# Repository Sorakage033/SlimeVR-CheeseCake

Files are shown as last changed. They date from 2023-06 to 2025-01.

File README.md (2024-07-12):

Intro-GIF 

# SlimeVR-CheeseCake
Very delicious Cheesecake. Designed by Sorakage

# OverView
"CheeseCake" is a Lighter, portable and better looking full body tracking device.   
Based on SlimeVR   
With 8-port charging dock, eliminating wiring troubles.   
# CAUTION：   
**When you place an order in JLCPCB, remember change the PCB thickness to 1mm!**    
    
**Before flashing the firmware, the board must be connected to the battery.**    
This design removes the protection diode (to prevent Li-po battery overcharged while uploading firmware), and USB-5V is supplied to the battery via the on-board charging chip TP4057.    
**The on-board charger will not output voltage without connected to the battery.**        
## Extra Info:      
Any kind of modification are welcome!         
It can be even better if you can credit me on the modified PCB with [\[This LOGO\]](999-PictureFiles/SK-LOGO.png)     

## Index
- [Components](#Components)
- [Versions](#Versions)
- [Printing](#Printing)
- [Assembly](#Assembly)
- [Support Link](#Support)

## Components 
For the CheeseCake you will need the following components:   
- PCB produced by JLC PCBA   
- 3D Print Parts   
- 38 or 40mm straps   
-   Li-po Battery (_803035 800/900mAh or 903035 1000/1200mAh is what the docs suggest_)
    -   **Ensure the battery is no larger than 9mm in depth, 30mm in width, and 35mm in height to fit the case.**
    -   **Verify the battery dimensions with the seller before purchase. Some sellers list 803035 batteries with dimensions exceed, which will not fit in the 3D printed case.**
- Pogo Pins (Optional for specific supported PCBs) [\[More Info\]](001-‘’Cheese‘’/POGOPIN%20purchase%20Link.txt)
- Soldering Iron/Station 

## Versions
There are lots of Variations of PCB included in this Project:     

### 1st Anniversary Special Edition
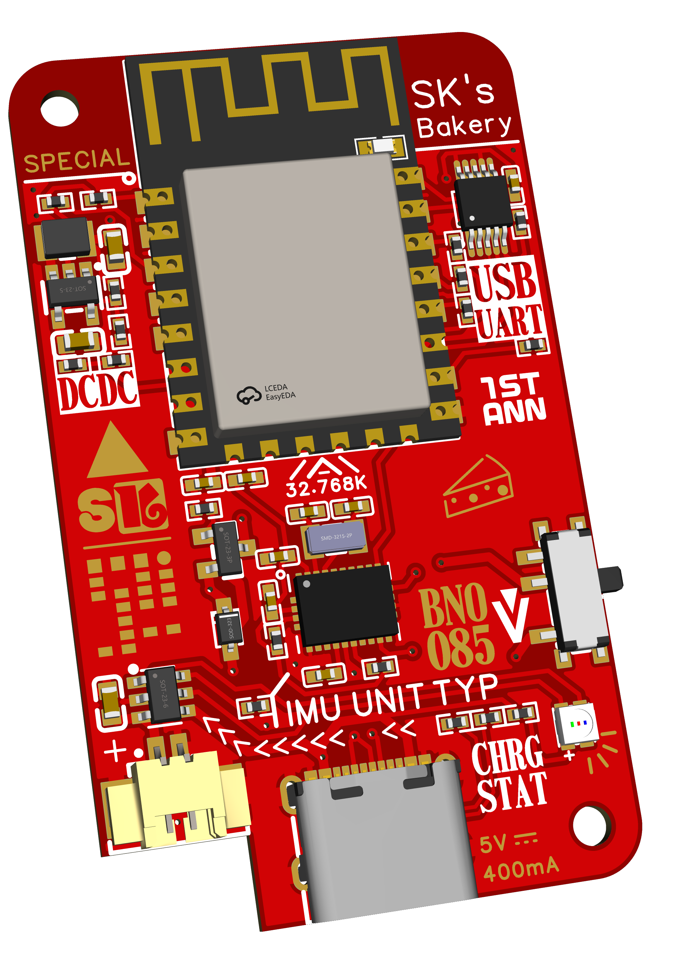
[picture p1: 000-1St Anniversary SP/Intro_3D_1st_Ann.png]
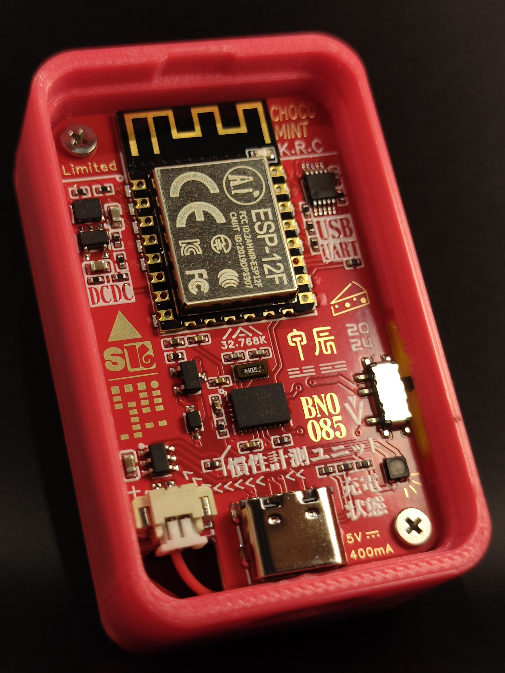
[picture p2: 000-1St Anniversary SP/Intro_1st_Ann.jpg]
      

It's been a year since the release of the cheesecake. To thank everyone for actively participating in enjoying cheesecakes, a special 1st Anniversary edition was released!    
It includes: BNO085(SMT Type), DC-DC Buck, and battery connector(JST 1.25mm)!

### BMI270-「Cheese RV」
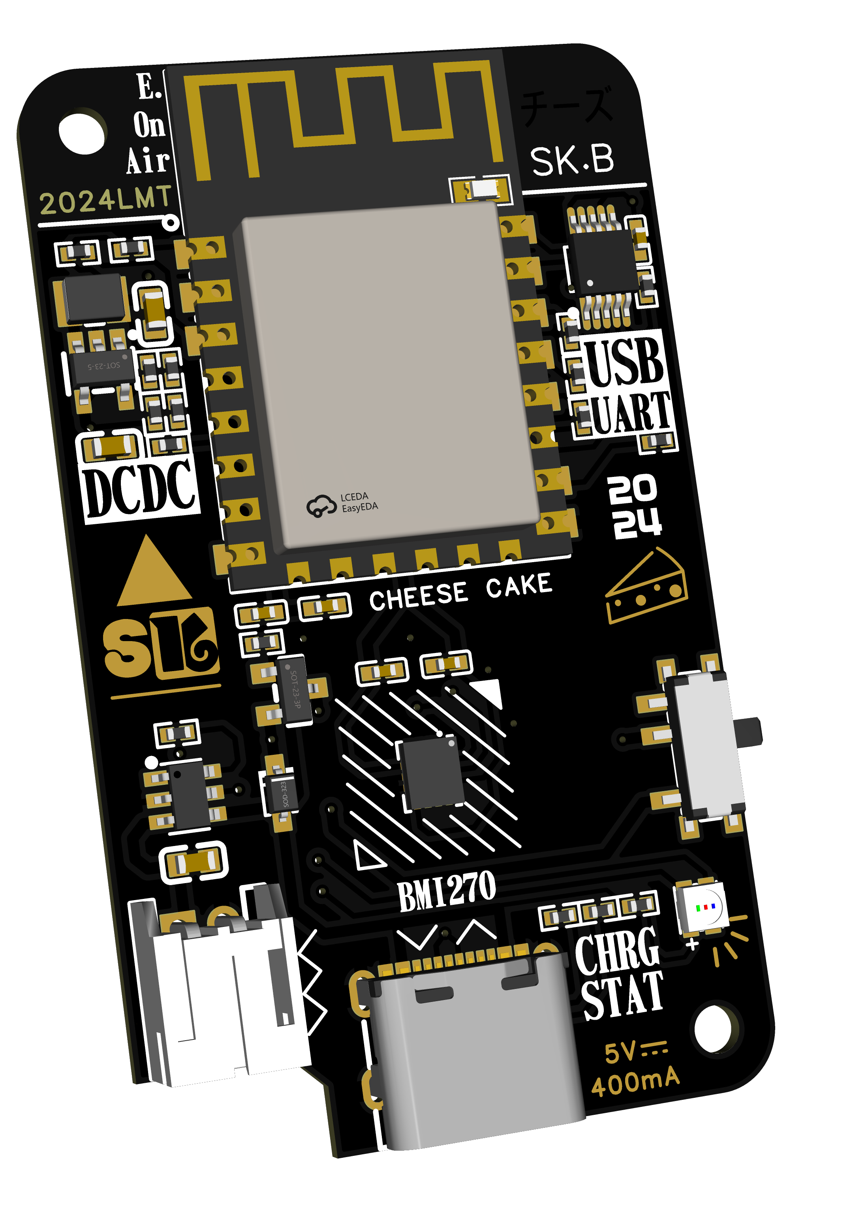
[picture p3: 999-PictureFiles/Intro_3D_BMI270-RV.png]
   

Because BMI160 is EOL now, Update a BMI270 version, it has a JST 2.0mm battery connector(Battery+ is left) and reverse to match Type-C Charging Dock.      
But it doesn't include AUX connector, if you want make a BMI270 with AUX, check "Cheese with AUX".       

### BNO085-「Choco」SpecialRemake
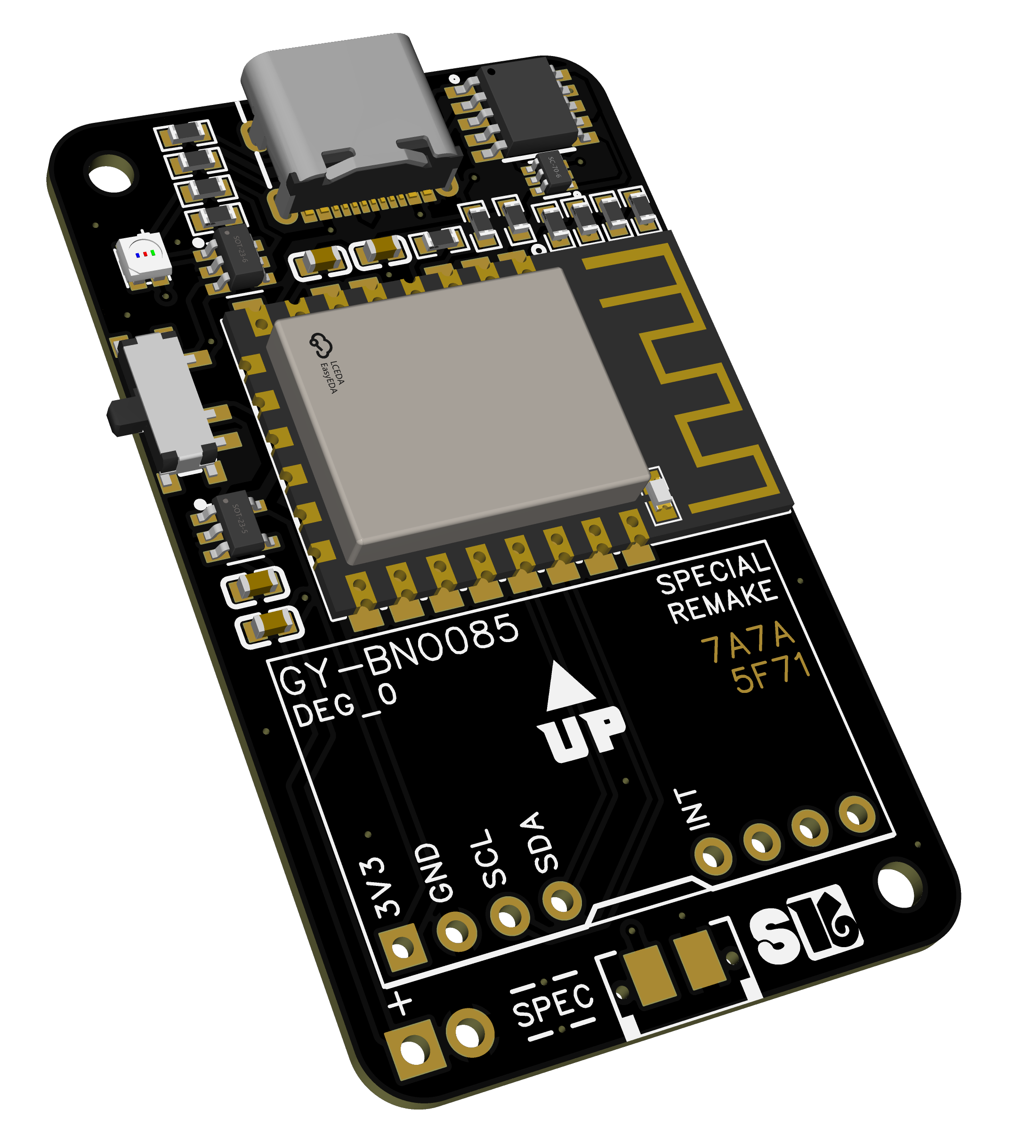
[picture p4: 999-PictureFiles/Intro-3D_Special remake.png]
    

### BNO085-「Choco」SpecialRemake(With AUX port)
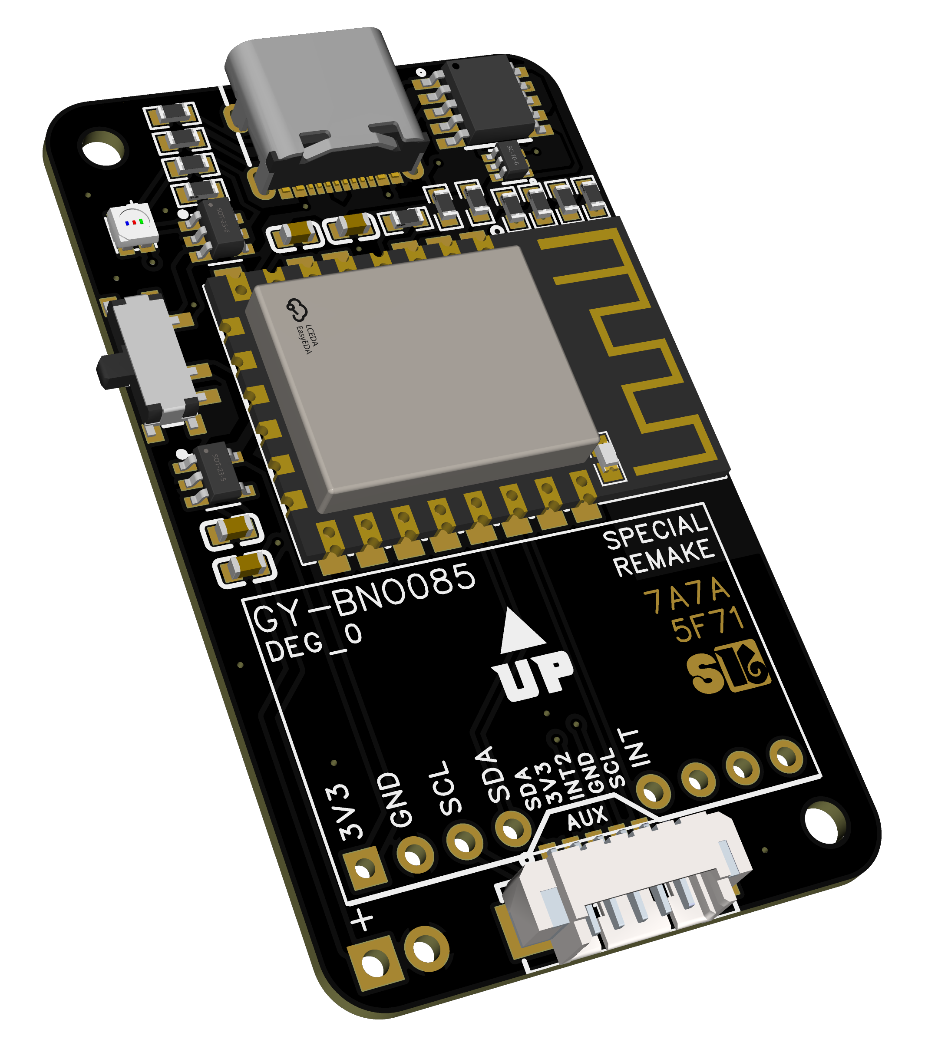
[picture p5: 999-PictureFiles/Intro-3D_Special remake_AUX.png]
    

### BNO085-「Choco」SpecialRemake(With AUX port and DC-DC Buck power supply)    
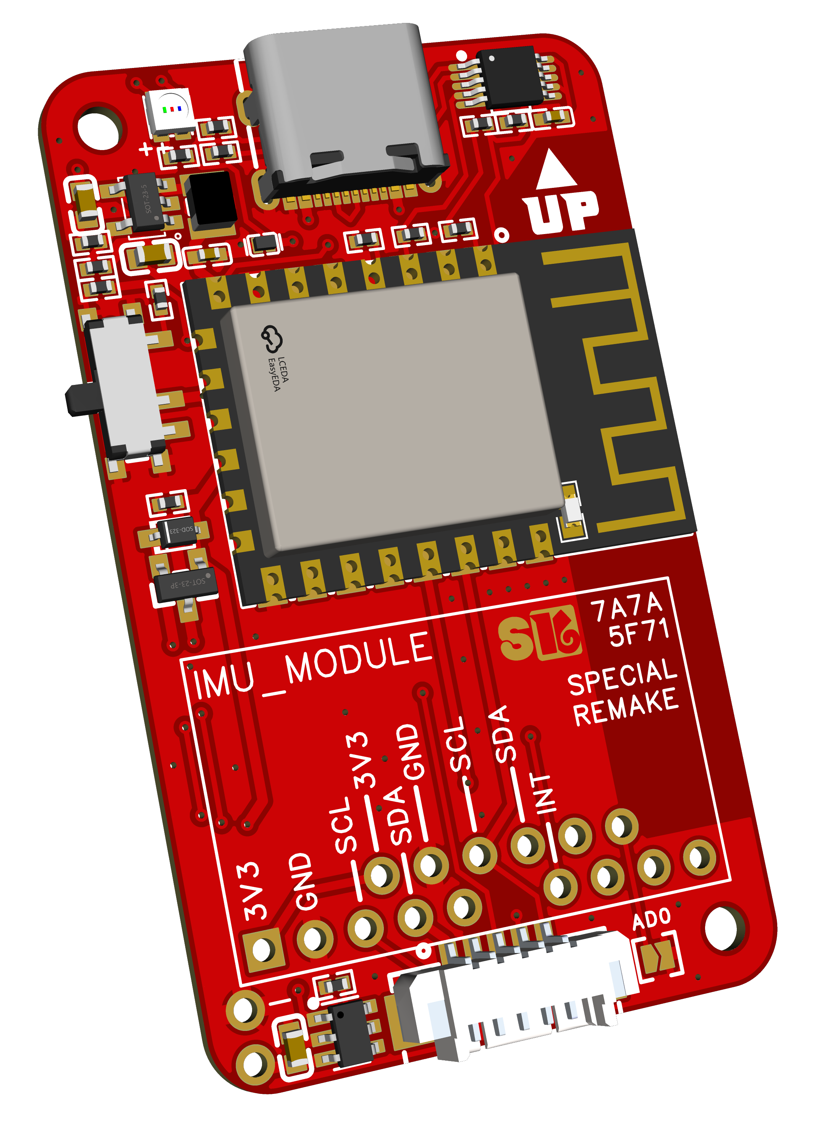
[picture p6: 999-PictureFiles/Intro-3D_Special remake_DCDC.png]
      

This might be the best CheeseCake ever. To extend the battery life, it have some magic in it:    
DC-DC Buck Power Supply, which can save up to 18% of power consumption (in 4.2V,LDO need 90mA, but DC-DC only need 74mA).    
And in order to improve signal quality over long distances, leave some Keep-out area at ESP-12F's antenna.    
While using this version, the code in ``define.h`` must be change to:      
```
    #elif BOARD == BOARD_NODEMCU || BOARD == BOARD_WEMOSD1MINI
      #define PIN_IMU_SDA D2
      #define PIN_IMU_SCL D1
      #define PIN_IMU_INT D5
      #define PIN_IMU_INT_2 D6
      #define PIN_BATTERY_LEVEL A0
      #ifndef BATTERY_SHIELD_RESISTANCE
        #define BATTERY_SHIELD_RESISTANCE 0
      #endif
      #ifndef BATTERY_SHIELD_R1 
        #define BATTERY_SHIELD_R1 10
      #endif
      #ifndef BATTERY_SHIELD_R2
        #define BATTERY_SHIELD_R2 47
      #endif    
```      

### LSM6DSV-「Blueberry」(With DC-DC Buck power supply and Battery connector)      
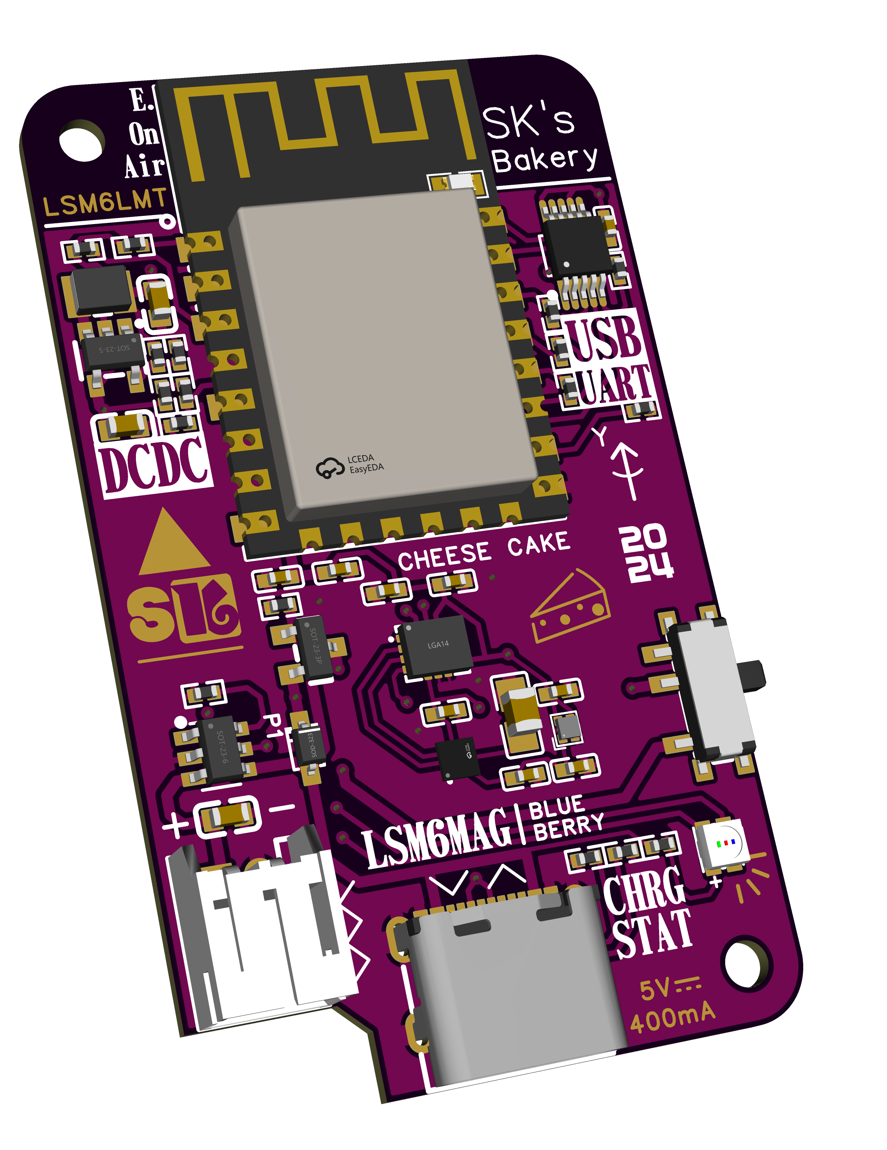
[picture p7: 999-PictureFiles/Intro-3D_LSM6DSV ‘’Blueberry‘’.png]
      

The new version of LSM6DSV includes a battery connector and a magnetometer, which may provide better tracking performance and relieve those who want to make their own tracker from the hassle of soldering.       
The battrey connector have 2 types to choose: JST2.0mm and JST1.25mm. Regardless of the type of connector, the positive of the battery is always on the left side.      
But the AUX port was replaced by battery connector, if you want make LSM6 with AUX, check "Old_Version".      
**SPECIAL CAUTION**     
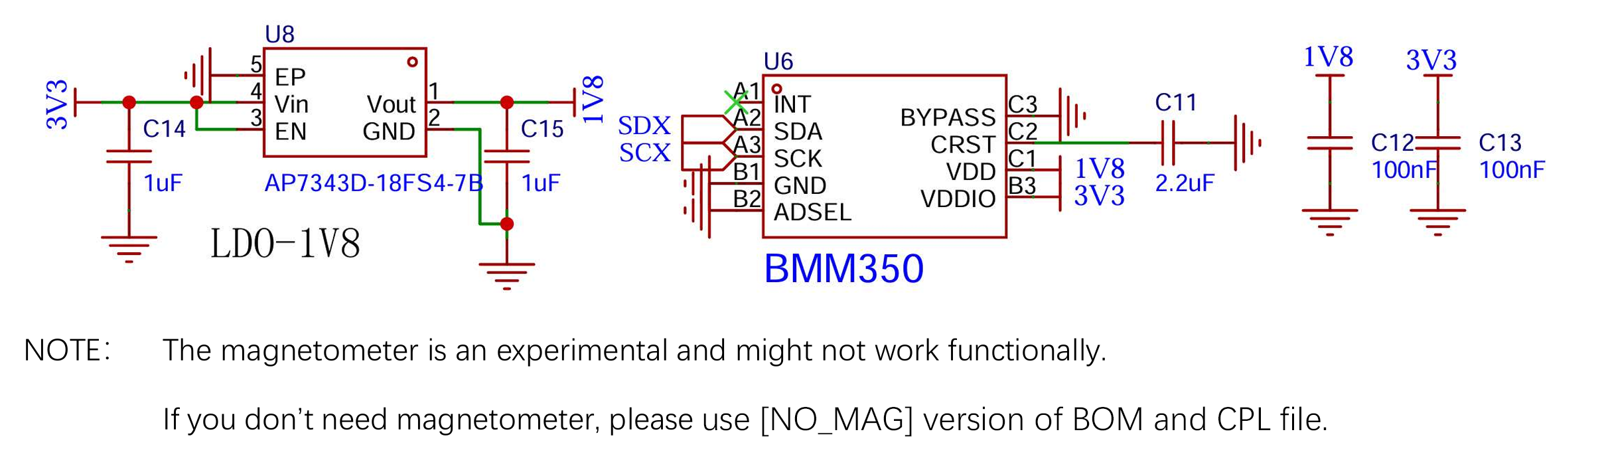
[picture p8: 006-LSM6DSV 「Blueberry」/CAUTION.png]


### ICM-42688-「RareCheese」(With external oscillator , AUX port and DC-DC Buck power supply)        
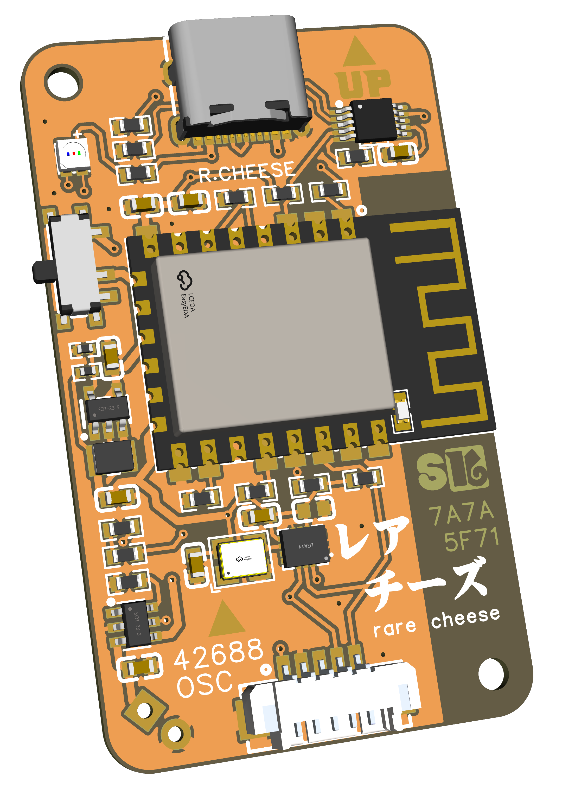
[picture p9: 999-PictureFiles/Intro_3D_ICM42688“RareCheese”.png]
          

All Japanese love Rare CheeseCake a lot, I love it too.      
And I hope you can also like it.    

### AUX MODULE - SK-MOD       

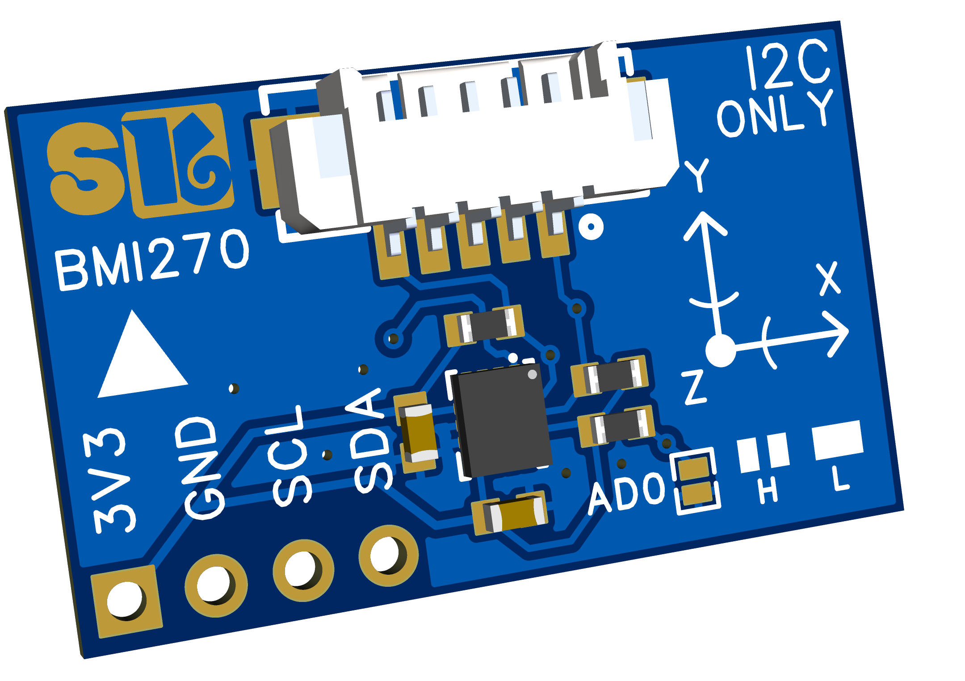
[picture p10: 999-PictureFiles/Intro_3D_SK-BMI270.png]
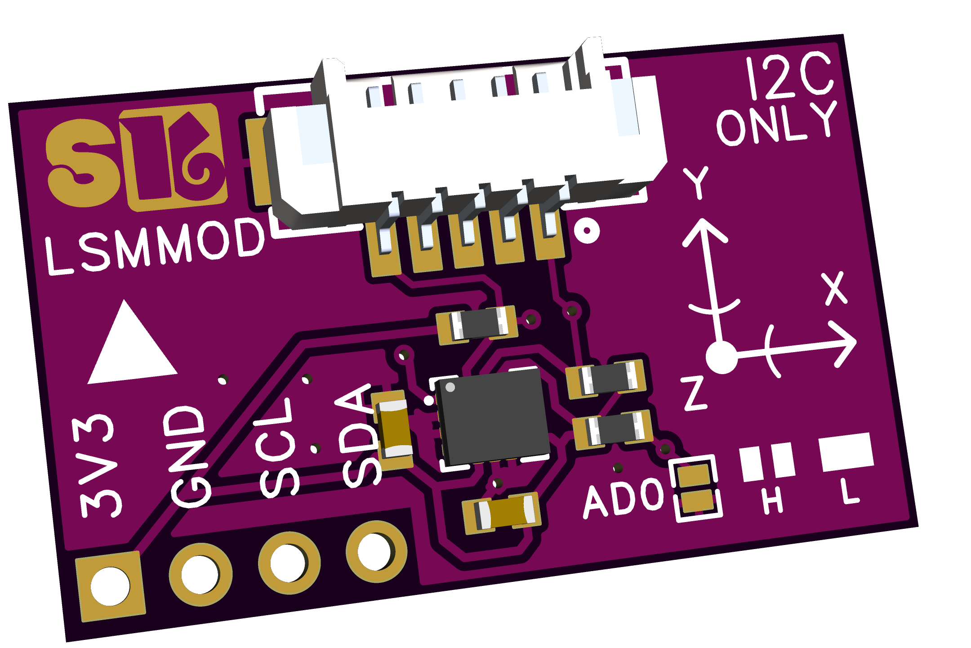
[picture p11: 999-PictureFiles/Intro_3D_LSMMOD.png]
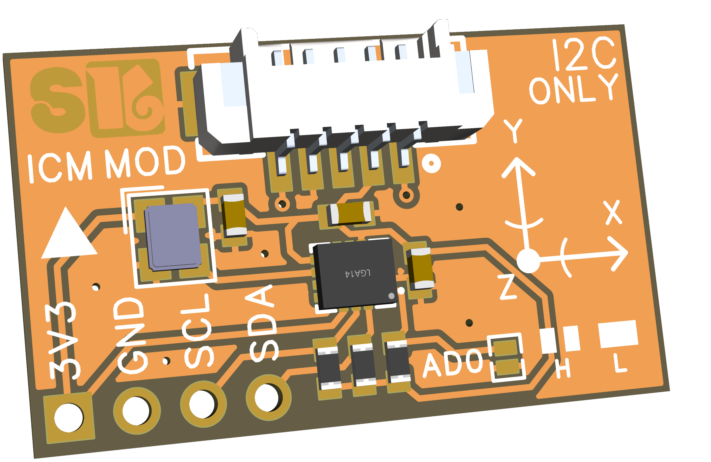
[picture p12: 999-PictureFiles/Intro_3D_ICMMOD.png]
      
Including 3 different MOD: BMI series, LSM6DSV series and ICM-42688(with External Clock)

```
In SK-BMI MOD, the default IMU on BMI MOD is BMI270, but you can change it to BMI160/BMI323 or other IMUs at PCBA page.
```
It can be solodered on 「Choco」SpecialRemake directly or connect to the AUX port through ``JST 1.25mm 5pin`` like pic below:      
Note: the two connectors are MIRROR      
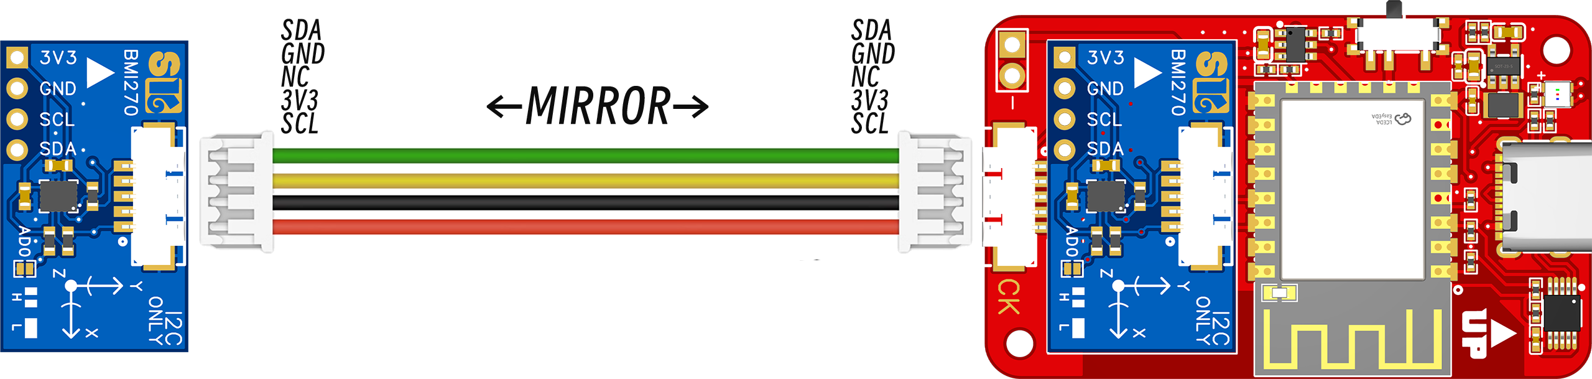
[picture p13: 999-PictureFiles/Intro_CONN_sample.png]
       
- **Notice:If you want to use it both solder it on Choco-SpecialRemake and use as AUX, I recommend order JST connector separately and soldering them on by yourself.**       
- **With AUX connector it too thick to fix acrylic top lid, or you need to carve a groove in the corresponding position of the 3D print top lid.**    

And the DEG of this module is fixed to ``DEG_0`` when installed on 「Choco」SpecialRemake or Y axis towards up.        

Also, if you want to upgrade your SlimeVR but not using 「Choco」SpecialRemake, it has a smaller version of SK-BMI270:     
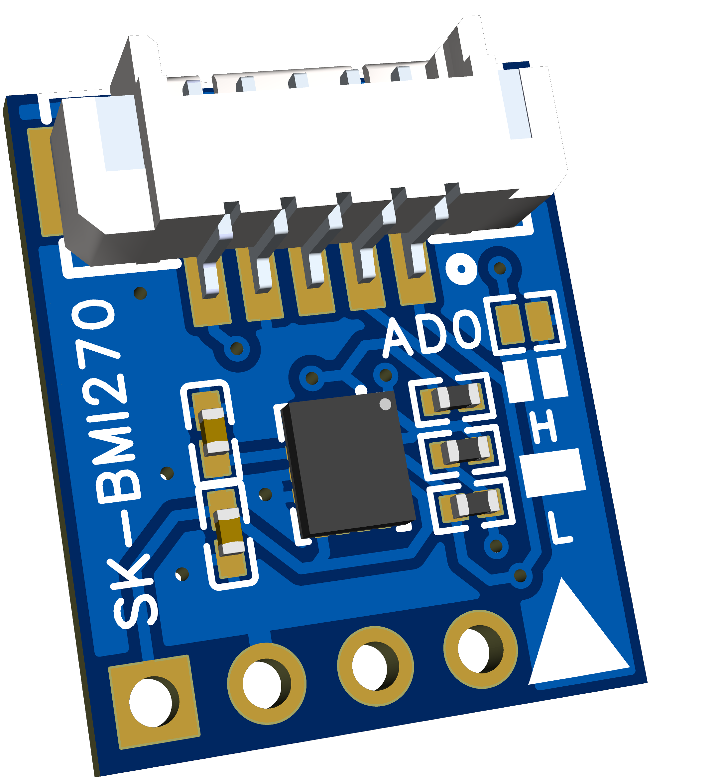
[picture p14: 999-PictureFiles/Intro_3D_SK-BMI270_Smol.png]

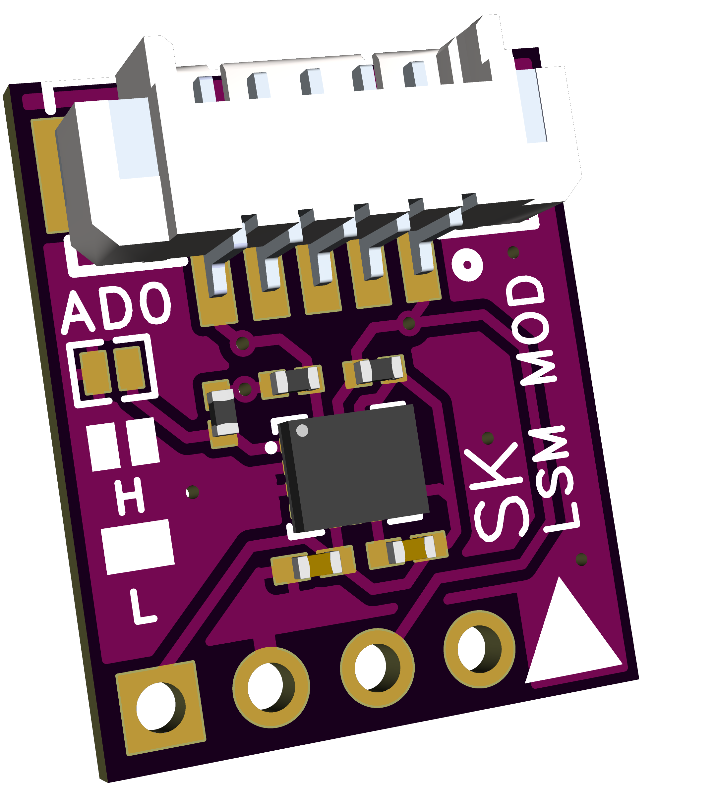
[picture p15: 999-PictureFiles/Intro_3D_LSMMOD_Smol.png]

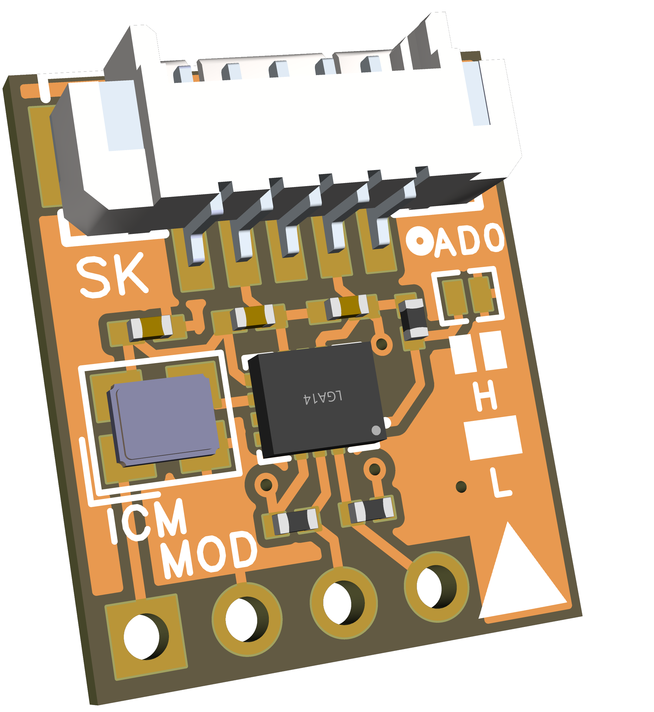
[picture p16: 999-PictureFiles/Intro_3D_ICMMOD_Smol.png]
      
Though it has a smaller size, if it was soldered on 「Choco」SpecialRemake, it looks a little bit unbalance.      

## 3D Printing for SlimeVR-CheeseCake

This repository contains various 3D printed components required to assemble the SlimeVR-CheeseCake. Below are the necessary files and instructions.

### CheeseCake Case
- **Main Case**: [CheeseCake Case with AUX](https://github.com/Sorakage033/SlimeVR-CheeseCake/blob/main/004-3D%20Print%20Model/001.2-Chocolate-Case-With-AUX.stl) - Recommended design compatible with any 3D filament.
- **Alternative Designs**:
  - [Case with USB Port Only](https://github.com/Sorakage033/SlimeVR-CheeseCake/blob/main/004-3D%20Print%20Model/001.3-Chocolate-Case_TypeC-Only.stl)
  - [Case with Pogo Pins Cutout](https://github.com/Sorakage033/SlimeVR-CheeseCake/blob/main/004-3D%20Print%20Model/001.1-Chocolate-Case.stl)    
  - [Case for Knurled Insert Nuts](https://github.com/Sorakage033/SlimeVR-CheeseCake/blob/main/004-3D%20Print%20Model/001.4-Chocolate-Case_Type-C-only_insert-nuts.stl)
    - Size of Knurled Insert Nut is `M2*5*3.5 ( M2xOD3.5, 5mm Length )` like [This](https://www.aliexpress.us/item/1005004431154591.html)
    - No pogo pins cutout or AUX cutout, for new designs.
- If you want a larger battery, you can use the [803040-case](https://github.com/Sorakage033/SlimeVR-CheeseCake/tree/main/004-3D%20Print%20Model/000.1-Blue-Compact-Case-For-803040-Bat) modified by Blu3u.

### Top Lid
- **3D Printed Option**: [3D Printed Top Lid](https://github.com/Sorakage033/SlimeVR-CheeseCake/blob/main/004-3D%20Print%20Model/002-Cake-Top.stl)
- Note: Use elephant foot compensation to reduce fitting issues.
- **Acrylic Option**: For a 4mm transparent acrylic lid, use the dimensions provided in [this file](https://github.com/Sorakage033/SlimeVR-CheeseCake/blob/main/004-3D%20Print%20Model/AcrylicTop-CutSize-Thickness4mm.png).

### Essential Component
- **Switch Component**: [Switch for Case](https://github.com/Sorakage033/SlimeVR-CheeseCake/blob/main/004-3D%20Print%20Model/003-SW.stl) - This part is crucial for the assembly.
- Note: If it's hard to assemble, you can try narrowing the switch by scaling down the Z-axis.

### Holders (Recommended to Print in PETG Filament)
- [Clamp Holder](https://github.com/Sorakage033/SlimeVR-CheeseCake/blob/main/004-3D%20Print%20Model/004-''CLAMP''Holder.stl) - Fits 4cm and 3cm straps.
- [Clamp Holder 5cm Strap](https://github.com/Sorakage033/SlimeVR-CheeseCake/blob/main/004-3D%20Print%20Model/004-2-''CLAMP''Holder-5cm.stl) - Fits 5cm straps.
- [GoPro Chest Harness Compatible Clamp Holder](https://github.com/Sorakage033/SlimeVR-CheeseCake/blob/main/004-3D%20Print%20Model/004-1-''CLAMP''GoPro_Holder.stl) - For GoPro chest harness compatibility.
- [Slide Holder](https://github.com/Sorakage033/SlimeVR-CheeseCake/blob/main/004-3D%20Print%20Model/005-''SLIDE''Holder.stl) - Fits 4cm and 3cm straps.
- [Slide Holder 5cm Strap](https://github.com/Sorakage033/SlimeVR-CheeseCake/blob/main/004-3D%20Print%20Model/005-1-''SLIDE''Holder-5cm.stl) - Fits 5cm straps.

### Charging Dock (Recommended to Build the Type-C ChargeDock)
- **8-Tracker Type-C ChargeDock**     
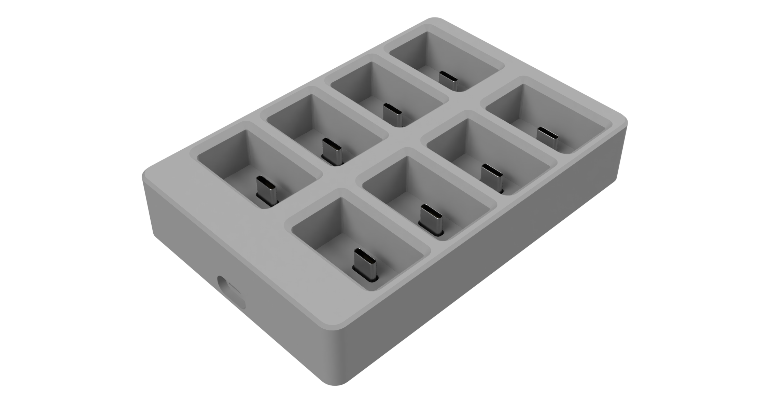
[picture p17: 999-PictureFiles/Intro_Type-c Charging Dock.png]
  
  - [Top Part](https://github.com/Sorakage033/SlimeVR-CheeseCake/blob/main/004-3D%20Print%20Model/ChargeDock-8port-Typec-Top.stl)
  - [Bottom Part](https://github.com/Sorakage033/SlimeVR-CheeseCake/blob/main/004-3D%20Print%20Model/ChargeDock-8port-Typec-Bottom.stl)
- **8-Tracker ChargeDock**:
  - [Top Part](https://github.com/Sorakage033/SlimeVR-CheeseCake/blob/main/004-3D%20Print%20Model/ChargeDock-8port-Top-Optimized.stl)
  - [Bottom Part](https://github.com/Sorakage033/SlimeVR-CheeseCake/blob/main/004-3D%20Print%20Model/ChargeDock-8port-Bottom-Optimized.stl)
- **6-Tracker ChargeDock**:
  - [Top Part](https://github.com/Sorakage033/SlimeVR-CheeseCake/blob/main/004-3D%20Print%20Model/ChargeDock-6port-Top.stl)
  - [Bottom Part](https://github.com/Sorakage033/SlimeVR-CheeseCake/blob/main/004-3D%20Print%20Model/ChargeDock-6port-Bottom.stl)

## Assembly    
    
1.  Apply about 2cm foam tape on the inner side of the case. Install two M2*7mm hexagonal spacers (either with a HAMMER, or push the spacer into the hole with a soldering iron to melt it in place)      
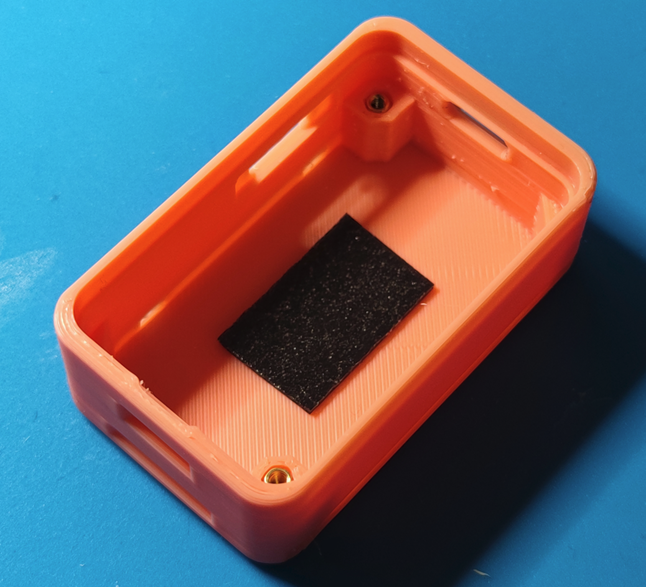
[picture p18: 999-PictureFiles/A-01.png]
     
2.  Place the switch part in position and affix the battery to the case.
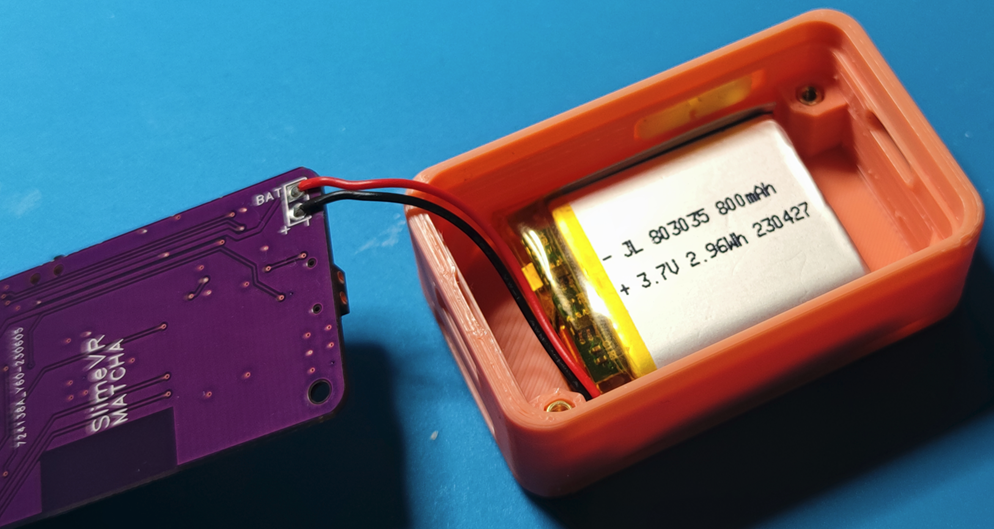
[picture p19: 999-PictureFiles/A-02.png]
    
3.  Bend the battery wire to ensure it can be tucked into the reserved gap during installation.    
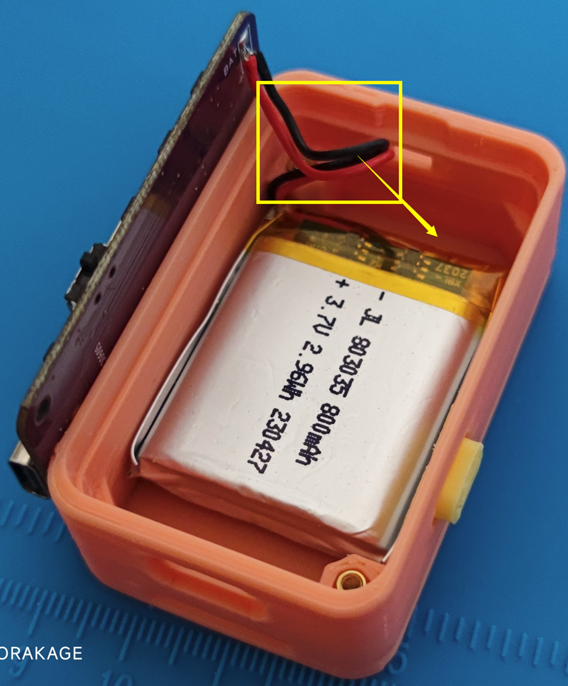
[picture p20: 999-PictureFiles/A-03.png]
    
4.  When installing the PCB, put the switch to the "UP" position, tilt it towards the side with the switch. Fit it into the reserved slot on the 3d printing part. It is extremely easy to break this switch!    
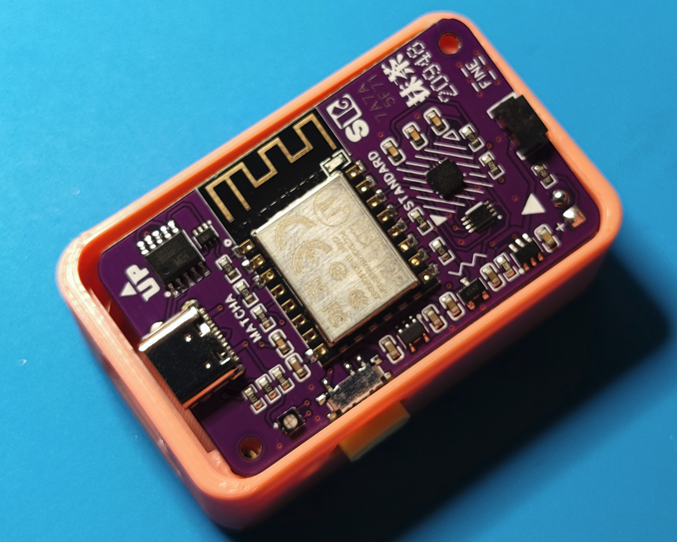
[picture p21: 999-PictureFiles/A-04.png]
    
5.  Tilt the board slightly towards the USB-C side, push the PCB at the side away from the switch.    
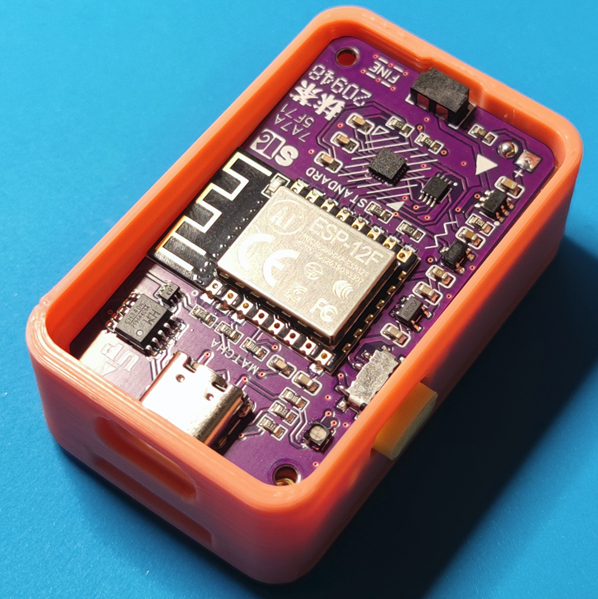
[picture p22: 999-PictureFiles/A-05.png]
     
6.  Press the whole PCB at position, screw on M2*5mm screws and pressure fit the cover.      
      
## Dock Assembly    

1.  Install M2*7mm hexagonal spacers into chargedock top piece. (either with a HAMMER, or push the spacer into the hole with a soldering iron to melt it in place).
3.  Insert PCB into chargedock bottom.
4.  Press the chargedock bottom into position, screw on M2*5mm screws.

## Support
If this project can help you I would be very happy!      
And also, if you want to give me some support, you can support me on [BOOTH](https://sorakage033.booth.pm/items/4859476)!

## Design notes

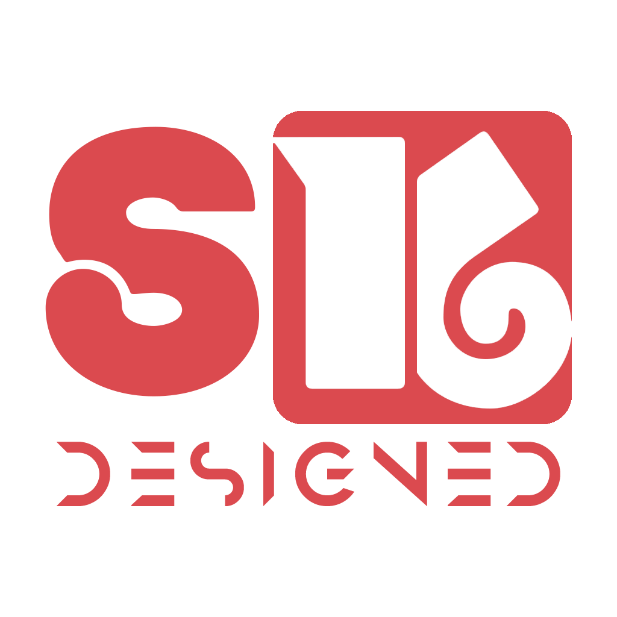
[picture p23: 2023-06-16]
Designed and Released By Sorakage.png

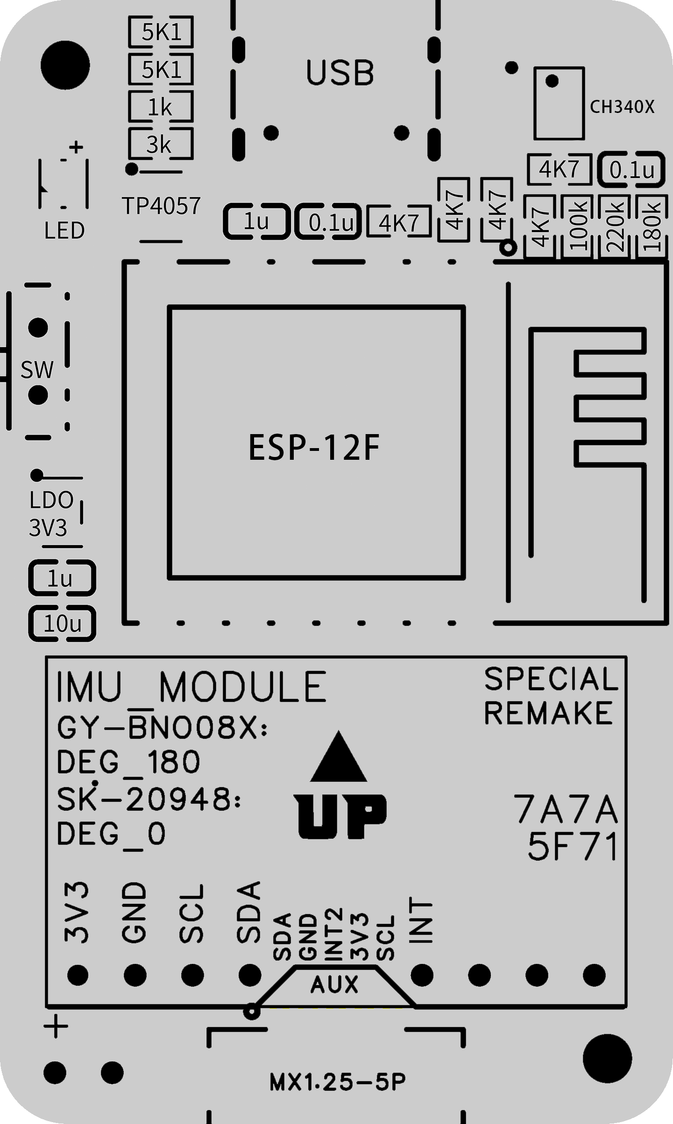
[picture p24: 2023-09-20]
002-‘’Choco‘’SpecialRemake/004-Footprint-module-085.png

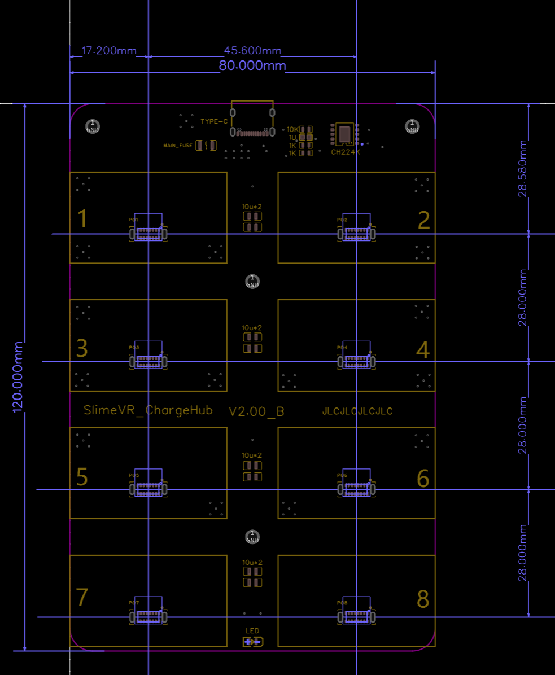
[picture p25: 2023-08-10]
003-Charging Dock/Type-c/Type-c Position.png

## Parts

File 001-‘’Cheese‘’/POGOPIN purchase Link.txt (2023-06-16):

//////FEMALE//////
￥ 155  13%OFF | 2pin Pogo Pin Connector Pitch 2.54mm Battery spring Loaded Contact Side Welding Test Probes Male Female Power Connector Plug (Ask for Female Only)
https://a.aliexpress.com/_mNQbnHQ

//////MALE//////
￥ 34  15%OFF | 1pcs Male / Female Spring Loaded Pogo pin header Target Connector 2.54mm Pitch 2p 3p 4p 5p 6p 7p 10p  Positions Through Hole PCB (A-6.0mm,2pin,male)
https://a.aliexpress.com/_mOHsa64

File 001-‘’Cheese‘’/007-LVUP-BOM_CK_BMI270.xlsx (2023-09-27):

No. | Quantity | Comment | Designator | Footprint | Value | Manufacturer Part | Manufacturer | Supplier Part | Supplier
2 | 3 | 1uF | C1,C4,C5 | C0603 | 1uF | CL10A105KB8NNNC | SAMSUNG(三星) | C15849 | LCSC
3 | 3 | 100nF | C2,C6,C7 | C0603 | 100nF | CL10B104KB8NNNC | SAMSUNG(三星) | C1591 | LCSC
4 | 1 | 10uF | CP | C0603 |  | CL10A106KP8NNNC | SAMSUNG(三星) | C19702 | LCSC
5 | 1 | 2.4GHz | ESP1 | WIFIM-SMD_ESP-12F-ESP8266MOD | 2.4GHz | ESP-12F(ESP8266MOD) | Ai-Thinker(安信可) | C82891 | LCSC
6 | 1 | BMI270 | IMU1 | LGA-14_L3.0-W2.5-P0.50-BR |  | BMI270 | Bosch(博世) | C2836813 | LCSC
7 | 1 | _ | J1 | footprint_179d
8 | 1 | ME6211C33M5G-N | LDO3V3 | SOT-23-5_L3.0-W1.7-P0.95-LS2.8-BL |  | ME6211C33M5G-N | MICRONE(南京微盟) | C82942 | LCSC
9 | 1 | NH-B2020RGBA-HF | LED | LED-ARRAY-SMD_4P-L2.1-W2.1-TL_NH-B2020RGBA |  | NH-B2020RGBA-HF | 国星光电 | C2874116 | LCSC
10 | 1 | TP4057-42-SOT26-R | P1 | SOT-23-6_L2.9-W1.6-P0.95-LS2.8-BL |  | TP4057-42-SOT26-R | TOPPOWER(南京拓微) | C12044 | LCSC
11 | 1 | UMH3N | Q1 | SC-70-6_L2.2-W1.3-P0.65-LS2.1-BR |  | UMH3N | CJ(江苏长电/长晶) | C62892 | LCSC
12 | 6 | 0603WAF4701T5E | R1,R2,R3,R4,R5,RD | R0603 |  | 0603WAF4701T5E | UNI-ROYAL(厚声) | C23162 | LCSC
13 | 1 | 0603WAF3001T5E | RA | R0603 |  | 0603WAF3001T5E | UNI-ROYAL(厚声) | C4211 | LCSC
14 | 2 | 5.1kΩ | RD1,RD2 | R0603 |  | 0603WAF5101T5E | UNI-ROYAL(厚声) | C23186 | LCSC
15 | 1 | 1kΩ | RL | R0603 |  | 0603WAF1001T5E | UNI-ROYAL(厚声) | C21190 | LCSC
16 | 1 | 0603WAF1803T5E | RS | R0603 |  | 0603WAF1803T5E | UNI-ROYAL(厚声) | C22827 | LCSC
17 | 1 | SSSS811101 | SW | SW-SMD_SSSS811101 |  | SSSS811101 | ALPSALPINE(阿尔卑斯阿尔派) | C109335 | LCSC
18 | 1 | CH340K | UART | ESOP-10_L4.9-W3.9-P1.00-LS6.2-BL-EP |  | CH340K | WCH(南京沁恒) | C968586 | LCSC
19 | 1 | TYPE-C 16PIN 2MD(073) | USB | USB-C-SMD_TYPE-C-6PIN-2MD-073 |  | TYPE-C 16PIN 2MD(073) | SHOU HAN(首韩) | C2765186 | LCSC
20 | 1 | 220kΩ | VD1 | R0603 |  | 0603WAF2203T5E | UNI-ROYAL(厚声) | C22961 | LCSC
21 | 1 | 100kΩ | VD2 | R0603 |  | 0603WAF1003T5E | UNI-ROYAL(厚声) | C25803 | LCSC

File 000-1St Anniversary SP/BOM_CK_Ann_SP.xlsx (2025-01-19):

No. | Quantity | Comment | Designator | Footprint | Value | Manufacturer Part | Manufacturer | Supplier Part | Supplier
1 | 1 | BNO080 | BNO085 | bno080 |  | BNO085 | Hillcrest | C5189642 | LCSC
2 | 1 | 1uF | C1 | C0402 | 1uF | CL05A105KA5NQNC | SAMSUNG(三星) | C52923 | LCSC
3 | 5 | 100nF | C2,C3,C8,C9,C10 | C0402 | 100nF | CL05B104KO5NNNC | SAMSUNG(三星) | C1525 | LCSC
4 | 2 | 10uF | C4,C5 | C0603 | 10uF | CL10A106KP8NNNC | SAMSUNG(三星) | C19702 | LCSC
5 | 2 | 22pF | C6,C7 | C0402 | 22pF | 0402CG220J500NT | FH(风华) | C1555 | LCSC
6 | 1 | 1.25-2PWB | CN1 | conn-smd_2p-p1.25_dealon_1.25-2pwb |  | 1.25-2PWB | DEALON(德艺隆) | C2905009 | LCSC
7 | 1 | 10uF | CP1 | C0603 |  | CL10A106KP8NNNC | SAMSUNG(三星) | C19702 | LCSC
8 | 1 | 1N5819WS | D1 | SOD-323_L1.8-W1.3-LS2.5-RD |  | 1N5819WS | Hottech(合科泰) | C191023 | LCSC
9 | 1 | 2.4GHz | ESP1 | wifim-smd_esp-12f-esp8266mod | 2.4GHz | ESP-12F(ESP8266MOD) | Ai-Thinker(安信可) | C82891 | LCSC
10 | 1 | 22kΩ | FB1 | R0402 | 22kΩ | 0402WGF2202TCE | UNI-ROYAL(厚声) | C25768 | LCSC
11 | 1 | 100kΩ | FB2 | R0402 | 100kΩ | 0402WGF1003TCE | UNI-ROYAL(厚声) | C25741 | LCSC
12 | 1 | 2.2uH | L1 | IND-SMD_L2.5-W2.0_YXMBL252010P | 2.2uH | APH252010T2R2M | APV(爱普微) | C5349606 | LCSC
13 | 1 | NH-B2020RGBA-HF | LED1 | LED-ARRAY-SMD_4P-L2.1-W2.1-TL_NH-B2020RGBA |  | NH-B2020RGBA-HF | 国星光电 | C2874116 | LCSC
14 | 1 | TP4057-42-SOT26-R | P1 | SOT-23-6_L2.9-W1.6-P0.95-LS2.8-BL |  | TP4057-42-SOT26-R | TOPPOWER(南京拓微) | C12044 | LCSC
15 | 1 | AO3401A | Q1 | SOT-23_L2.9-W1.3-P1.90-LS2.4-BR |  | AO3401A | AOS | C15127 | LCSC
16 | 8 | 4.7kΩ | R1,R2,R3,R4,R5,R7,R8,RD3 | R0402 | 4.7kΩ | 0402WGF4701TCE | UNI-ROYAL(厚声) | C25900 | LCSC
17 | 3 | 10kΩ | R6,R9,VDG | R0402 | 10kΩ | 0402WGF1002TCE | UNI-ROYAL(厚声) | C25744 | LCSC
18 | 1 | 2kΩ | RA1 | R0402 | 2kΩ | 0402WGF2001TCE | UNI-ROYAL(厚声) | C4109 | LCSC
19 | 2 | 5.1kΩ | RD1,RD2 | R0402 | 5.1kΩ | 0402WGF5101TCE | UNI-ROYAL(厚声) | C25905 | LCSC
20 | 1 | 1kΩ | RL1 | R0402 | 1kΩ | 0402WGF1001TCE | UNI-ROYAL(厚声) | C11702 | LCSC
21 | 1 | SSSS811101 | SW1 | SW-SMD_SSSS811101 |  | SSSS811101 | ALPSALPINE(阿尔卑斯阿尔派) | C109335 | LCSC
22 | 1 | MT3406 | U1 | SOT-23-5_L3.0-W1.7-P0.95-LS2.8-BR |  | MT3406 | 西安航天民芯 | C22462728 | LCSC
23 | 1 | CH340X | UART1 | MSOP-10_L3.0-W3.0-P0.50-LS5.0-BL |  | CH340X | WCH(南京沁恒) | C3035748 | LCSC
24 | 1 | TYPE-C 16PIN 2MD(073) | USB1 | USB-C-SMD_TYPE-C-6PIN-2MD-073 |  | TYPE-C 16PIN 2MD(073) | SHOU HAN(首韩) | C2765186 | LCSC
25 | 1 | 47kΩ | VDV | R0402 | 47kΩ | 0402WGF4702TCE | UNI-ROYAL(厚声) | C25792 | LCSC
26 | 1 | 32.768kHz | X1 | FC-135R_L3.2-W1.5 | 32.768kHz | Q13FC1350000400 | EPSON(爱普生) | C32346 | LCSC

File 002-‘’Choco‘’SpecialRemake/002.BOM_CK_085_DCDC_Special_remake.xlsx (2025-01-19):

No. | Quantity | Comment | Designator | Footprint | Value | Manufacturer Part | Manufacturer | Supplier Part | Supplier
1 | 2 | 100nF | C2,C3 | C0402 | 100nF | CL05B104KO5NNNC | SAMSUNG(三星) | C1525 | LCSC
2 | 2 | 10uF | C4,C5 | C0603 | 10uF | CL10A106KP8NNNC | SAMSUNG(三星) | C19702 | LCSC
3 | 1 | HC-1.25-5PWT | CN1 | conn-smd_5p-p1.25_hctl_hc-1.25-5pwt |  | HC-1.25-5PWT | HCTL(华灿天禄) | C2845382 | LCSC
4 | 1 | 10uF | CP1 | C0603 |  | CL10A106KP8NNNC | SAMSUNG(三星) | C19702 | LCSC
5 | 1 | 1N5819WS | D1 | SOD-323_L1.8-W1.3-LS2.5-RD |  | 1N5819WS | Hottech(合科泰) | C191023 | LCSC
6 | 1 | 2.4GHz | ESP1 | WIFIM-SMD_ESP-12F-ESP8266MOD | 2.4GHz | ESP-12F(ESP8266MOD) | Ai-Thinker(安信可) | C82891 | LCSC
7 | 1 | 22kΩ | FB1 | R0402 | 22kΩ | 0402WGF2202TCE | UNI-ROYAL(厚声) | C25768 | LCSC
8 | 1 | 100kΩ | FB2 | R0402 | 100kΩ | 0402WGF1003TCE | UNI-ROYAL(厚声) | C25741 | LCSC
9 | 1 | 2.2uH | L1 | IND-SMD_L2.5-W2.0_MHCHL2520 | 2.2uH | FTC252012S2R2MBCA | cjiang(长江微电) | C5832372 | LCSC
10 | 1 | NH-B2020RGBA-HF | LED1 | LED-ARRAY-SMD_4P-L2.1-W2.1-TL_NH-B2020RGBA |  | NH-B2020RGBA-HF | 国星光电 | C2874116 | LCSC
11 | 1 | TP4057-42-SOT26-R | P1 | SOT-23-6_L2.9-W1.6-P0.95-LS2.8-BL |  | TP4057-42-SOT26-R | TOPPOWER(南京拓微) | C12044 | LCSC
12 | 1 | ESD5451N | Q1 | X1-DFN1006-2_L1.0-W0.6-P0.65-BI |  | ESD5451N | TECH PUBLIC(台舟) | C2936977 | LCSC
13 | 1 | AO3401A | Q2 | SOT-23_L2.9-W1.3-P1.90-LS2.4-BR |  | AO3401A | AOS | C15127 | LCSC
14 | 5 | 4.7kΩ | R1,R2,R3,R4,RD3 | R0402 | 4.7kΩ | 0402WGF4701TCE | UNI-ROYAL(厚声) | C25900 | LCSC
15 | 2 | 10kΩ | R9,VDG | R0402 | 10kΩ | 0402WGF1002TCE | UNI-ROYAL(厚声) | C25744 | LCSC
16 | 1 | 2kΩ | RA1 | R0402 | 2kΩ | 0402WGF2001TCE | UNI-ROYAL(厚声) | C4109 | LCSC
17 | 2 | 5.1kΩ | RD1,RD2 | R0402 | 5.1kΩ | 0402WGF5101TCE | UNI-ROYAL(厚声) | C25905 | LCSC
18 | 1 | 1kΩ | RL1 | R0402 | 1kΩ | 0402WGF1001TCE | UNI-ROYAL(厚声) | C11702 | LCSC
19 | 1 | SSSS811101 | SW | SW-SMD_SSSS811101 |  | SSSS811101 | ALPSALPINE(阿尔卑斯阿尔派) | C109335 | LCSC
20 | 1 | MT3406 | U1 | SOT-23-5_L3.0-W1.7-P0.95-LS2.8-BR |  | MT3406 | 西安航天民芯 | C22462728 | LCSC
21 | 1 | CH340X | UART1 | MSOP-10_L3.0-W3.0-P0.50-LS5.0-BL |  | CH340X | WCH(南京沁恒) | C3035748 | LCSC
22 | 1 | TYPE-C 16PIN 2MD(073) | USB | USB-C-SMD_TYPE-C-6PIN-2MD-073 |  | TYPE-C 16PIN 2MD(073) | SHOU HAN(首韩) | C2765186 | LCSC
23 | 1 | 47kΩ | VDV | R0402 | 47kΩ | 0402WGF4702TCE | UNI-ROYAL(厚声) | C25792 | LCSC

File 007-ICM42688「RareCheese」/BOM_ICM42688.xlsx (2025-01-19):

No. | Quantity | Comment | Designator | Footprint | Value | Manufacturer Part | Manufacturer | Supplier Part | Supplier
2 | 1 | 1uF | C1 | C0603 |  | CL10A105KB8NNNC | SAMSUNG(三星) | C15849 | LCSC
3 | 5 | 100nF | C2,C4,C8,C9,C10 | C0603 |  | CC0603KRX7R9BB104 | YAGEO(国巨) | C14663 | LCSC
4 | 2 | 10uF | C5,C6 | C0603 | 10uF | CL10A106KP8NNNC | SAMSUNG(三星) | C19702 | LCSC
5 | 1 | 10uF | C7 | C0603 |  | CL10A106KP8NNNC | SAMSUNG(三星) | C19702 | LCSC
6 | 1 | HC-1.25-5PWT | CN1 | CONN-SMD_5P-P1.25_HCTL_HC-1.25-5PWT |  | HC-1.25-5PWT | HCTL(华灿天禄) | C2845382 | LCSC
7 | 1 | 22kΩ | FB1 | R0402 | 22kΩ | 0402WGF2202TCE | UNI-ROYAL(厚声) | C25768 | LCSC
8 | 1 | 100kΩ | FB2 | R0402 | 100kΩ | 0402WGF1003TCE | UNI-ROYAL(厚声) | C25741 | LCSC
9 | 1 | ICM-42688-P | IMU1 | LGA-14_L3.0-W2.5-P0.50-TL |  | ICM-42688-P | TDK InvenSense(应美盛) | C1850418 | LCSC
10 | 1 | 2.2uH | L1 | IND-SMD_L2.5-W2.0_YXMBL252010P | 2.2uH | APH252010T2R2M | APV(爱普微) | C5349606 | LCSC
11 | 1 | NH-B2020RGBA-HF | LED1 | LED-ARRAY-SMD_4P-L2.1-W2.1-TL_NH-B2020RGBA |  | NH-B2020RGBA-HF | 国星光电 | C2874116 | LCSC
12 | 1 | 32.768kHz | OSC1 | OSC-SMD_4P-L3.2-W2.5-BL | 32.768kHz | OK2EL89CJI-111YLC-32.768K | YXC(扬兴晶振) | C5280579 | LCSC
13 | 2 | 5.1kΩ | R1,R2 | R0603 |  | 0603WAF5101T5E | UNI-ROYAL(厚声) | C23186 | LCSC
14 | 7 | 4.7kΩ | R3,R4,R5,R6,R7,R8,R9 | R0603 |  | 0603WAF4701T5E | UNI-ROYAL(厚声) | C23162 | LCSC
15 | 1 | 100kΩ | R11 | R0603 | 100kΩ | 0603WAF1003T5E | UNI-ROYAL(厚声) | C25803 | LCSC
16 | 1 | 180kΩ | R12 | R0603 |  | 0603WAF1803T5E | UNI-ROYAL(厚声) | C22827 | LCSC
17 | 1 | 220kΩ | R13 | R0603 | 220kΩ | 0603WAF2203T5E | UNI-ROYAL(厚声) | C22961 | LCSC
18 | 1 | 1kΩ | R14 | R0603 |  | 0603WAF1001T5E | UNI-ROYAL(厚声) | C21190 | LCSC
19 | 1 | 2kΩ | R15 | R0603 | 2kΩ | 0603WAF2001T5E | UNI-ROYAL(厚声) | C22975 | LCSC
20 | 1 | SSSS811101 | SW1 | SW-SMD_SSSS811101 |  | SSSS811101 | ALPSALPINE(阿尔卑斯阿尔派) | C109335 | LCSC
21 | 1 | 2.4GHz | U1 | WIFIM-SMD_ESP-12F-ESP8266MOD | 2.4GHz | ESP-12F(ESP8266MOD) | Ai-Thinker(安信可) | C82891 | LCSC
22 | 1 | MT3406 | U2 | SOT-23-5_L3.0-W1.7-P0.95-LS2.8-BR |  | MT3406 | 西安航天民芯 | C22462728 | LCSC
23 | 1 | TP4057-42-SOT26-R | U3 | SOT-23-6_L2.9-W1.6-P0.95-LS2.8-BL |  | TP4057-42-SOT26-R | TOPPOWER(南京拓微) | C12044 | LCSC
24 | 1 | CH340X | UART1 | MSOP-10_L3.0-W3.0-P0.50-LS5.0-BL |  | CH340X | WCH(南京沁恒) | C3035748 | LCSC
25 | 1 | TYPE-C 16PIN 2MD(073) | USB1 | USB-C-SMD_TYPE-C-6PIN-2MD-073 |  | TYPE-C 16PIN 2MD(073) | SHOU HAN(首韩) | C2765186 | LCSC

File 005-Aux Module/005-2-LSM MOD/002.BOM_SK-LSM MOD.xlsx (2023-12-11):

No. | Quantity | Comment | Designator | Footprint | Value | Manufacturer Part | Manufacturer | Supplier Part | Supplier
1 | 2 | 100nF | C1,C2 | C0603 |  | CC0603KRX7R9BB104 | YAGEO(国巨) | C14663 | LCSC
2 | 1 | HC-1.25-5PWT | CN1 | CONN-SMD_5P-P1.25_HCTL_HC-1.25-5PWT |  | HC-1.25-5PWT | HCTL(华灿天禄) | C2845382 | LCSC
4 | 2 | 4.7kΩ | R3,R4 | R0603 |  | 0603WAF4701T5E | UNI-ROYAL(厚声) | C23162 | LCSC
5 | 1 | 10kΩ | R5 | R0603 | 10kΩ | 0603WAF1002T5E | UNI-ROYAL(厚声) | C25804 | LCSC
7 | 1 | LSM6DSV16XTR | U1 | LGA-14_L3.0-W2.5-P0.50-BR |  | LSM6DSV16XTR | ST(意法半导体) | C5267406 | LCSC

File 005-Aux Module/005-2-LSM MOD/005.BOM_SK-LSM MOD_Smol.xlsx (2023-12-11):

No. | Quantity | Comment | Designator | Footprint | Value | Manufacturer Part | Manufacturer | Supplier Part | Supplier
1 | 2 | 100nF | C1,C2 | C0402 | 100nF | CL05B104KO5NNNC | SAMSUNG(三星) | C1525 | LCSC
2 | 1 | HC-1.25-5PWT | CN1 | CONN-SMD_5P-P1.25_HCTL_HC-1.25-5PWT |  | HC-1.25-5PWT | HCTL(华灿天禄) | C2845382 | LCSC
4 | 2 | 4.7kΩ | R1,R2 | R0402 | 4.7kΩ | 0402WGF4701TCE | UNI-ROYAL(厚声) | C25900 | LCSC
5 | 1 | 10kΩ | R3 | R0402 | 10kΩ | 0402WGF1002TCE | UNI-ROYAL(厚声) | C25744 | LCSC
7 | 1 | LSM6DSV16XTR | U1 | LGA-14_L3.0-W2.5-P0.50-BR |  | LSM6DSV16XTR | ST(意法半导体) | C5267406 | LCSC

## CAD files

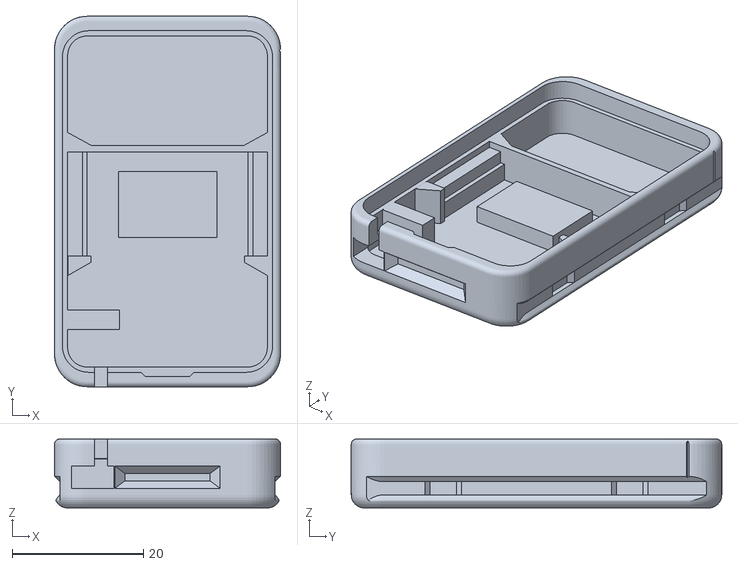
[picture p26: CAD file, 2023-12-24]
004-3D Print Model/000.1-Blue-Compact-Case-For-803040-Bat/ChocolateCase-LowProfile-For-Secondary-IMU-Experimental.stl
34.4 x 56.4 x 10.5

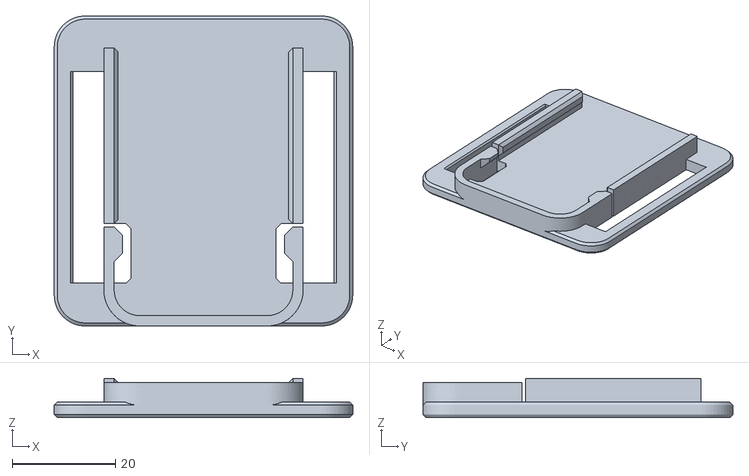
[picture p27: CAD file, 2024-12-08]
004-3D Print Model/005-2-''SLIDE''Holder-wide.stl
57.8 x 60.0 x 7.60

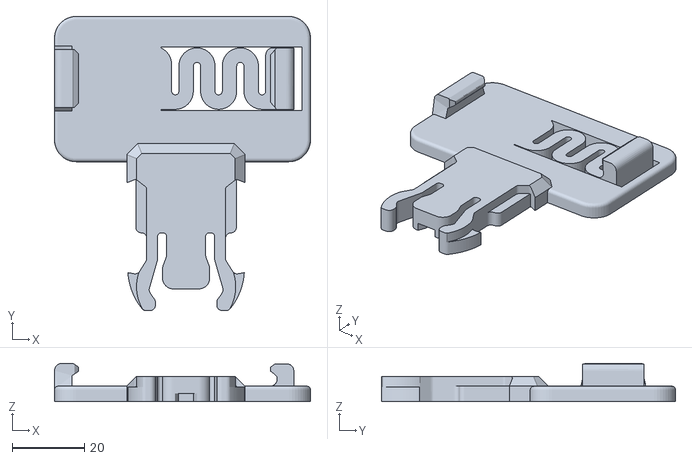
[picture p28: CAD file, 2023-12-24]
004-3D Print Model/000.1-Blue-Compact-Case-For-803040-Bat/ClampHolder-MoreDurable-For-GoPro.stl
70.8 x 81.4 x 10.6

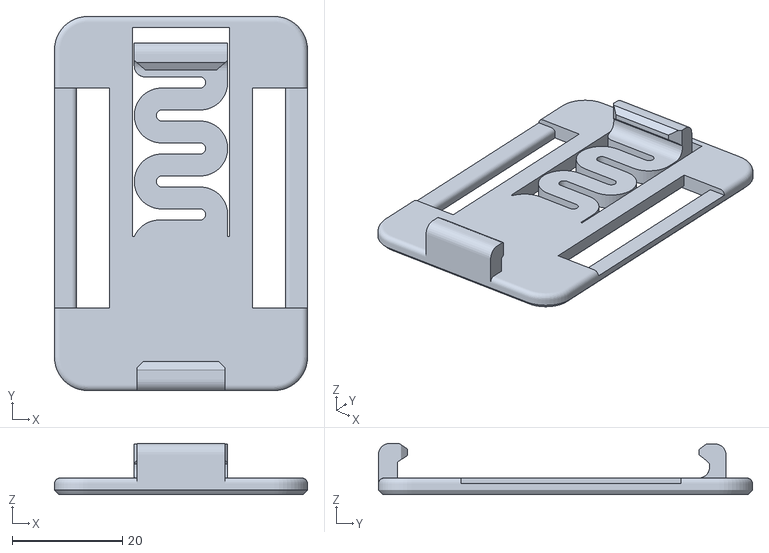
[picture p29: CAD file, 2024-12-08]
004-3D Print Model/004-3-''CLAMP''Holder-wide.stl
46.0 x 68.0 x 9.30

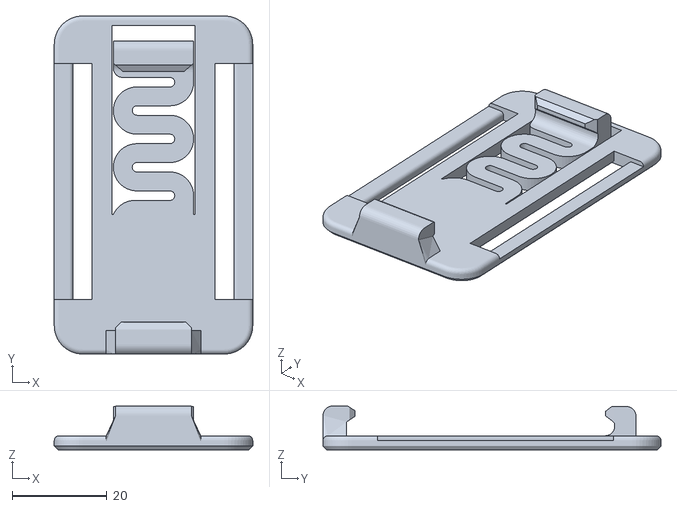
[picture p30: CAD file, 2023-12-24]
004-3D Print Model/000.1-Blue-Compact-Case-For-803040-Bat/ClampHolder-MoreDurable-For-5cm-Straps.stl
42.0 x 71.5 x 9.30

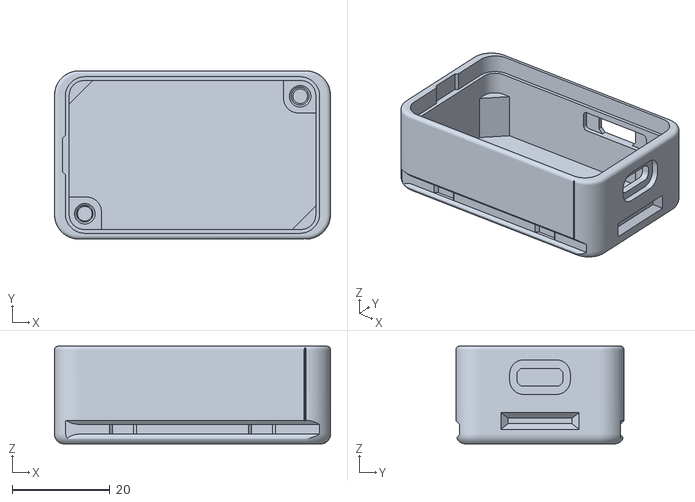
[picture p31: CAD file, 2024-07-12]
004-3D Print Model/001.4-Chocolate-Case_Type-C-only_insert-nuts.stl
56.4 x 34.4 x 20.0

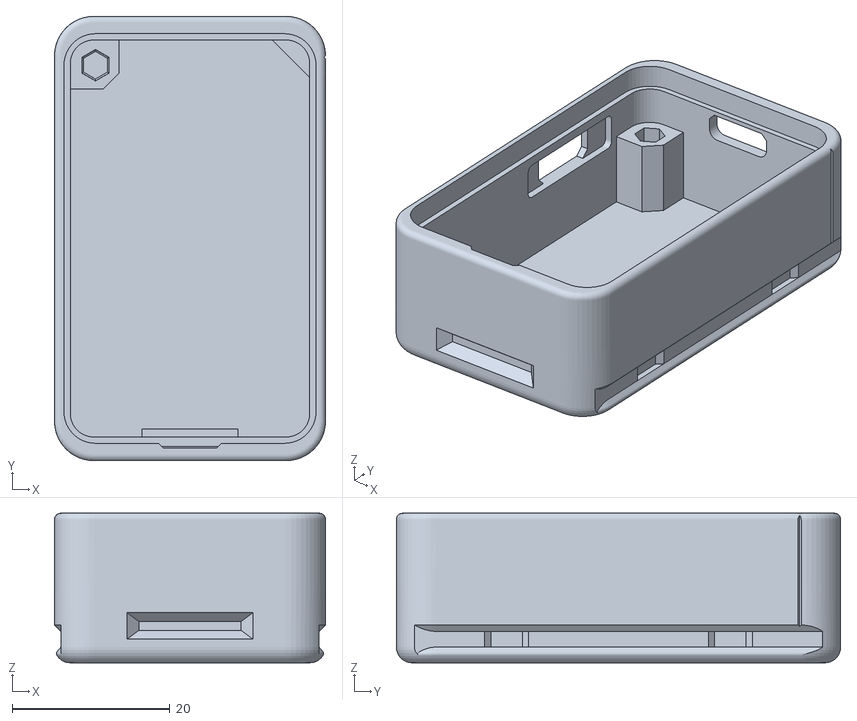
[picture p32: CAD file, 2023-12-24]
004-3D Print Model/000.1-Blue-Compact-Case-For-803040-Bat/ChocolateCase-For-803040-Bat.stl
34.4 x 56.4 x 19.0

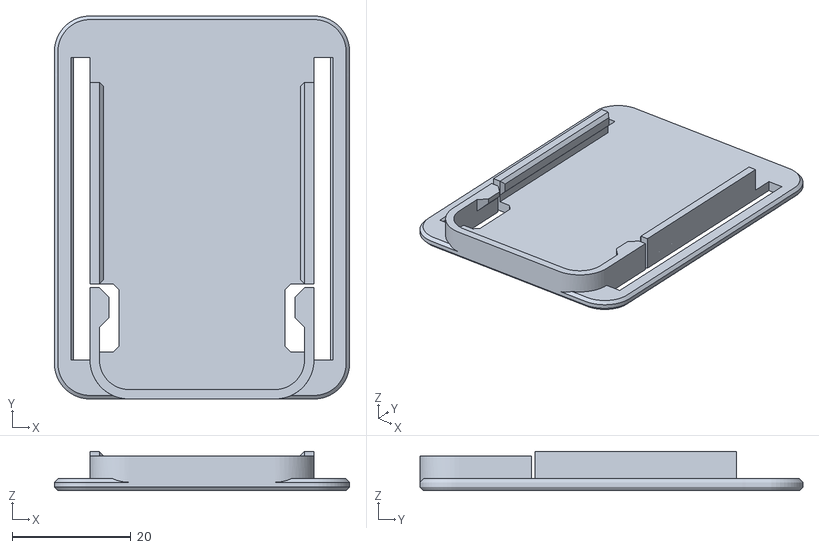
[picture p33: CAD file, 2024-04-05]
004-3D Print Model/005-1-''SLIDE''Holder-5cm.stl
49.8 x 64.6 x 6.60

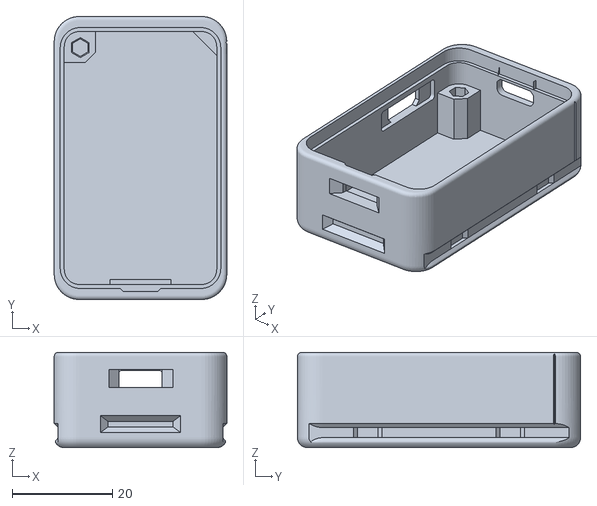
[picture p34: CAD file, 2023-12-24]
004-3D Print Model/000.1-Blue-Compact-Case-For-803040-Bat/ChocolateCase-For-803040-Bat-With-AUX.stl
34.4 x 56.4 x 19.0

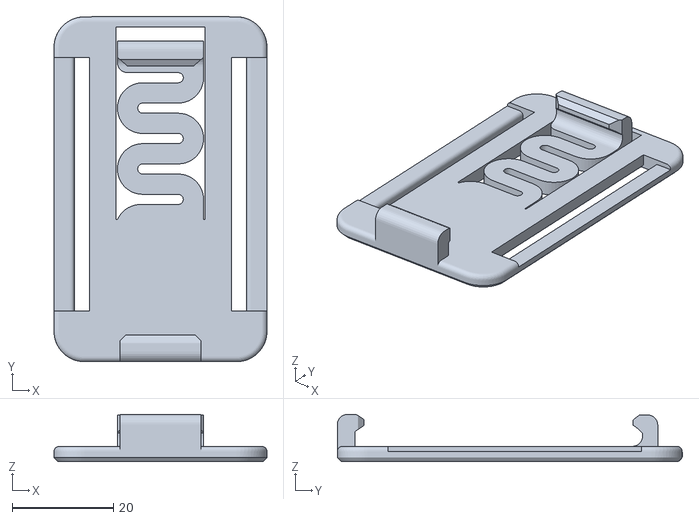
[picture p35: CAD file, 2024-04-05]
004-3D Print Model/004-2-''CLAMP''Holder-5cm.stl
42.0 x 68.1 x 9.30

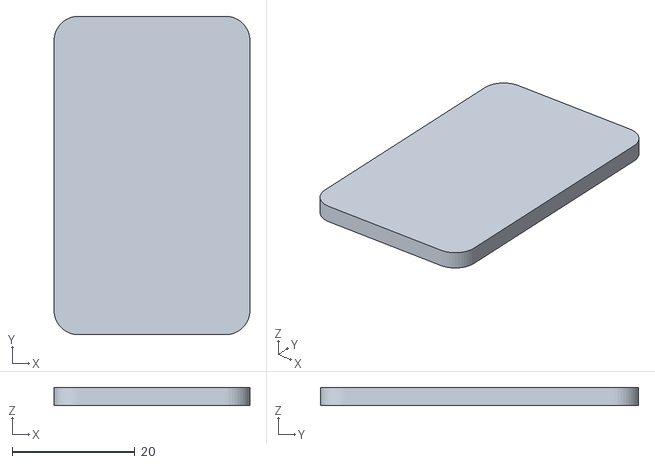
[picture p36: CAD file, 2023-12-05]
004-3D Print Model/000.1-Blue-Compact-Case-For-803040-Bat/CakeTop-Filament-3mm.stl
32.0 x 52.0 x 3.00

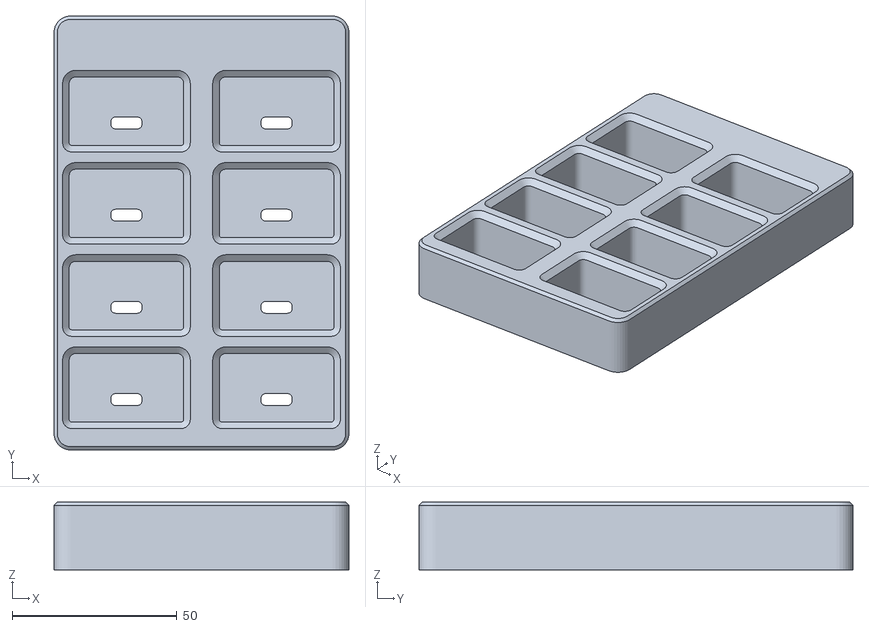
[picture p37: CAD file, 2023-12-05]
004-3D Print Model/ChargeDock-8port-Typec-Top.stl
89.6 x 131.8 x 20.6

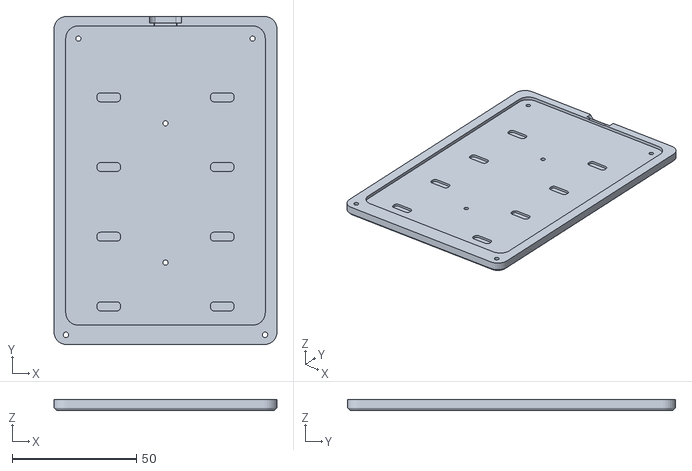
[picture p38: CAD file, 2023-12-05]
004-3D Print Model/ChargeDock-8port-Typec-Bottom.stl
89.6 x 131.8 x 4.40

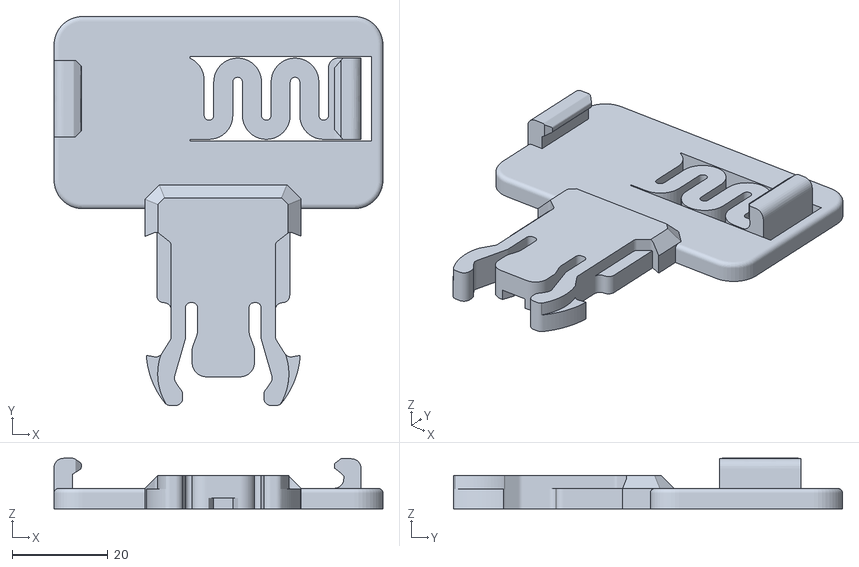
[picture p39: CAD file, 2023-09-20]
004-3D Print Model/004-1-''CLAMP''GoPro_Holder.stl
68.8 x 81.4 x 10.6

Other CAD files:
004-3D Print Model/001.3-Chocolate-Case_TypeC-Only.stl
004-3D Print Model/ChargeDock-8port-Top-Optimized.stl
004-3D Print Model/ChargeDock-6port-Top.stl
004-3D Print Model/ChargeDock-6port-Bottom.stl
004-3D Print Model/001.1-Chocolate-Case.stl
004-3D Print Model/001.2-Chocolate-Case-With-AUX.stl
004-3D Print Model/002-Cake-Top.stl
004-3D Print Model/003-SW.stl
004-3D Print Model/004-''CLAMP''Holder.stl
004-3D Print Model/005-''SLIDE''Holder.stl
004-3D Print Model/ChargeDock-8port-Bottom-Optimized.stl
004-3D Print Model/ChargeDock-8port-Top.stl

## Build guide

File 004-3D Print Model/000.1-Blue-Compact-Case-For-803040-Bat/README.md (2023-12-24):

# Blue Compact Case for 803040 Bat

This is a slightly modified version of the original case to use a larger battery, and secondary IMU.

I've made several minor improvements to the 3D models specifically for FDM printing, enhancing their durability.

## Why

- Made for larger 803040 Li-Po battery that appears to be easier to purchase in the EU.
- SlimeVR docs recommend 5cm-wide straps that were incompatible with CheeseCake.
- I did not use acrylic tops, and 4mm case top was problematic while using FDM.
- There were no CheeseCake case 3d models for secondary IMU.

## Features

### Chocolate Case

- Support for 803040 Li-Po that is larger: Now it's 1000mAh instead of 800mAh.
- Support for both original 4cm clamp/slide holders, and the 5cm versions from this directory.

### Chocolate Case for Secondary IMU

- Support for Secondary IMU case that is compatible with the CheeseCake design and holders.
- Low profile while retaining the compatibility with all existing CheeseCake holders.

### Clamp Holder

- Support for default SlimeVR recommended Amazon-sourced Trilancer straps: 5cm instead of 4cm width.
- Improved durability of the major weak spots in clamp holders.

## Assembly guide

Make sure that your filament is at least PETG, kept in a good condition, printed with optimal settings, and preferably with 100% infill modifier at weak spots - as shown in the screenshot. This slightly reduces the risk of breakage. Better safe than sorry!

HolderPrusa

- Print the cases: `USBC` regular, `USBC+AUX` regular, and `AUX low profile` for secondary IMU variants.
- Print the 3mm case top lids.
- Use the M2 screws. I intentionally kept the single screw hole near USBC port. It prevents the board from shifting.
- (optional) Use gorilla tape on the secondary IMU. In my case it wasn't necessary but I kept the cuboid intended for the tape in the final print.
- (optional) Print the holders for 5cm straps. Remember to measure your straps before printing.



I'm happy with the result. I hope the models will be useful.

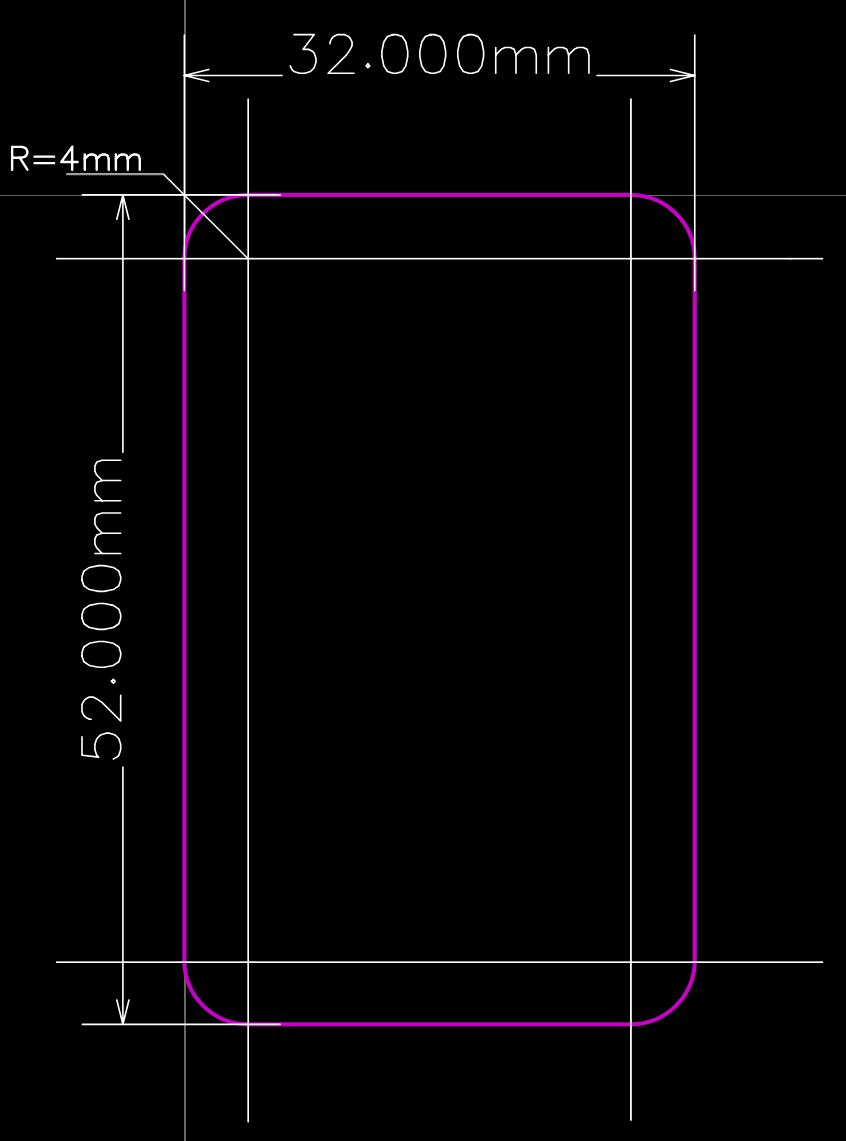
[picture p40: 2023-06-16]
004-3D Print Model/AcrylicTop-CutSize-Thickness4mm.png

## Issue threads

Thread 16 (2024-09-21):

Cheese RV - M3406-ADJ, please replace with MT9216

ShirBlackspots, 2024-09-21:
JCLPCB does not have a large inventory of the M3406-ADJ.  It has a unique pin out compared to other similar chips, such as the MT9216.  Could the PCB be revised to use the MT9216, which JCLPCB has a large inventory of (both have the same specs, just different pinout)

Traces using the XI'AN Aerosemi Tech M3406-ADJ
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

Traces using the XI'AN Aerosemi Tech MT9216
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
The Shouding SD8916A will also work in its place

I do not know how to properly export this so JCLPCB sees it correctly.

Also, JCLPCB does not have inventory of the inductor APV APH252010T2R2M.  It can be safely replaced with FH (Guangdong Fenghua Advanced Tech) PIM252010-2R2MTS00, which has the same specs

Sorakage033, 2024-09-22:
You can use TI's TLV62569DBVR (C141836) instead, they are pin-to-pin compatible.

ShirBlackspots, 2024-09-22:
Thank you very much!

Closed 2024-11-09.

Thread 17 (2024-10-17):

Aux Modules epro files

k8188219, 2024-10-17:
I am new to PCB design and want to create a board includes three different IMUs and possibly add a LOD similar to BMI160.

Could you share the epro files for the Aux Modules?

I hope to use them as a starting point for modifications and as reference material.

Thanks!

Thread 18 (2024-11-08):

ESP12F is now a "standard assembly only" part on JLCPCB

Caseritto, 2024-11-08:
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

As the title states, this steeply increases the cost of JLCPCB assembly as "economic assembly" is no longer an option with this part in the component list.

Any possible solutions or do we just have to bear the added cost now?

Sorakage033, 2024-11-09:
It’s possible that ESP-12F is no longer supported because it may get damaged under economic PCBA. Here are three solutions:

1. Since ESP-12F is not too difficult to solder, if you have a soldering iron or heat plate, you might choose to skip PCBA assembly and assemble it yourself (though this may require extra time).

2. There are still ESP-12F modules that can be used with economic PCBA, such as C784365 or C19949064. However, these are generally out of stock. You can use global sourcing or similar options to purchase them and have them sent to your personal warehouse at JLCPCB, then select them as replacements during PCBA.

3. Based on feedback from many DIY enthusiasts, using economic PCBA assembly can increase the DOA (Dead on Arrival) rate, with extreme cases reporting a DOA rate as high as 20/30. So if you are unable to repair PCBs yourself, it’s better to opt for standard PCBA, which will save you from a lot of hassle.

Caseritto, 2024-11-09:
Appreciate the response, will look into all available options

Closed 2024-12-07.

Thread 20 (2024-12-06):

RareCheese - C83224, low stock

kvalek, 2024-12-06:
JLCPCB has a low stock on the C83224 (M3406-ADJ). Is the C22462728 (MT3406) a suitable replacement?

Sorakage033, 2024-12-07:
Yes of course, and you can also use TI's TLV62569DBVR (C141836) instead, they are pin-to-pin compatible.

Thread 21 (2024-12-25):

C173752 charging connector out of stock what to use instead?

ShadowyNekoUwU, 2024-12-25:
Hello on JLCPCB it says they have an inventory shortage of the charging connector
C173752 what can I use instead? Thank you

Closed 2025-01-01.

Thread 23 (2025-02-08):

Documentation for pinouts needed for firmware config

kmatzen, 2025-02-08:
Hi, I was wondering where the pinouts required for defines.h in the firmware config was documented.  I opened the blueberry epro schematics and wrote down the pins, but I feel like I'm missing some markdown documentation that would have stated the config directly without going into the CAD files.  This repo seems to have all the manufacturing steps documented, so I was curious if the firmware docs should be here too.

Here's what the config looked like for blueberry.  Please let me know if I'm mistaken.

```
#define PIN_IMU_SDA 13
#define PIN_IMU_SCL 14
#define PIN_IMU_INT 5
#define PIN_IMU_INT_2
#define PIN_BATTERY_LEVEL 2
```

This doesn't appear to match any of the default configs that comes in defines.h.

Thanks!

Sorakage033, 2025-02-08:
The pin out is as same as wemosd1mini, you can use it directly.

kmatzen, 2025-02-08:
Thank you!

kmatzen, 2025-02-08:
Okay, I can see the mapping now.

SlimeVR alias -> platform alias -> GPIO alias -> physical pin
-----------------
PIN_IMU_SDA -> D2 -> GPIO4 -> pin 13
PIN_IMU_SCL -> D1 -> GPIO5 -> pin 14
PIN_IMU_INT -> D5 -> GPIO14 -> pin 5
PIN_BATTERY_LEVEL -> A0 -> ADC0 (17) -> pin 2

Closed 2025-02-08.

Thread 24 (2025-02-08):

Notes for 3D printing

kmatzen, 2025-02-08:
Are there any notes for 3D printing settings used for all the reference designs?  I didn't have any issues with the clamp design on default settings, but the slide design seems to have very little room for error.  I used PETG, set my layer height to 0.08mm for both the box and the slide and even then there was enough friction to make it difficult to insert and remove.  When I used the defaults on my slicer, the vertical restriction was enough to break the slide on insertion.

Thanks!

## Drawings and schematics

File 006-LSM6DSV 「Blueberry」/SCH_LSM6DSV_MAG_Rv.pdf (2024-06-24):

Type-c(Serial) | Main SW

## CHARGE

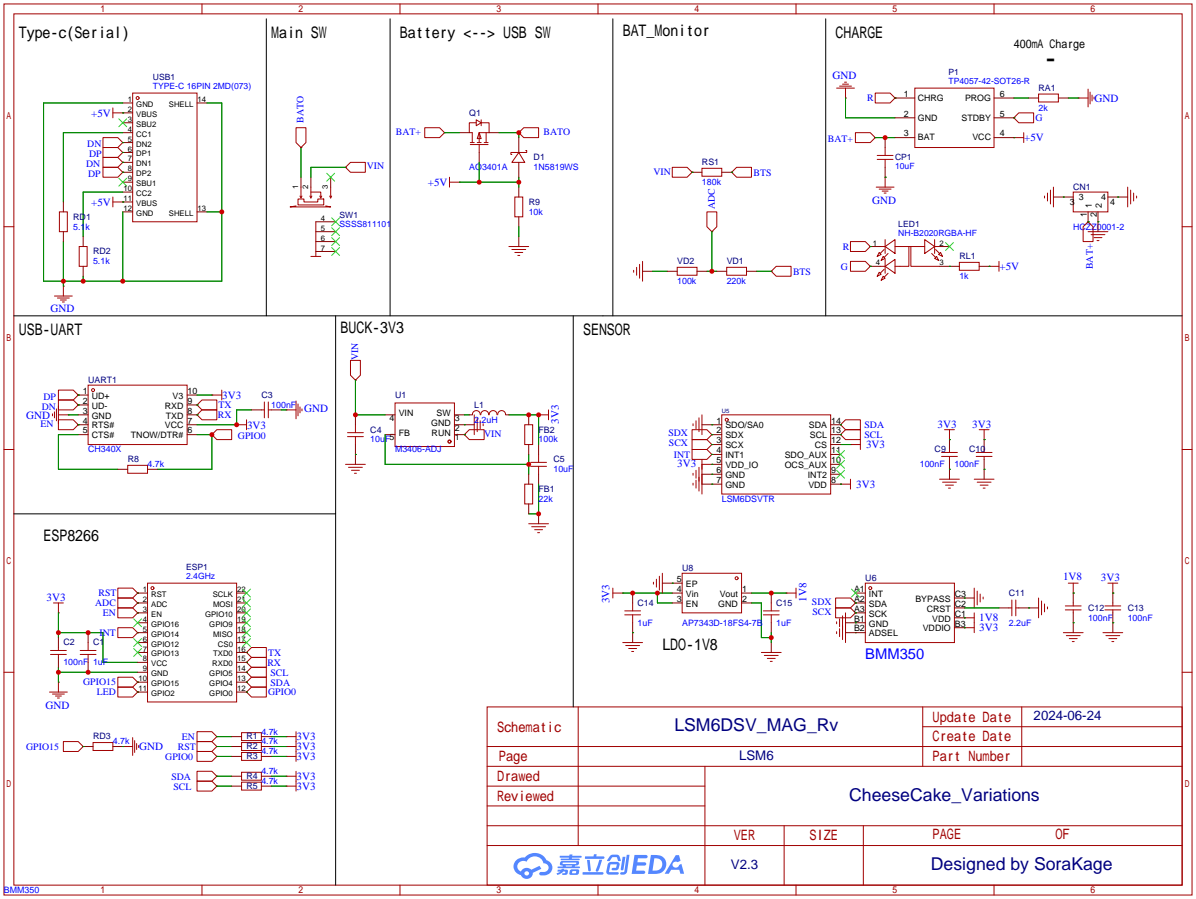
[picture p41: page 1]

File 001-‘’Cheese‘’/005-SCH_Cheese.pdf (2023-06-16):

Type-c(Serial) | Main SW

## CHARGE

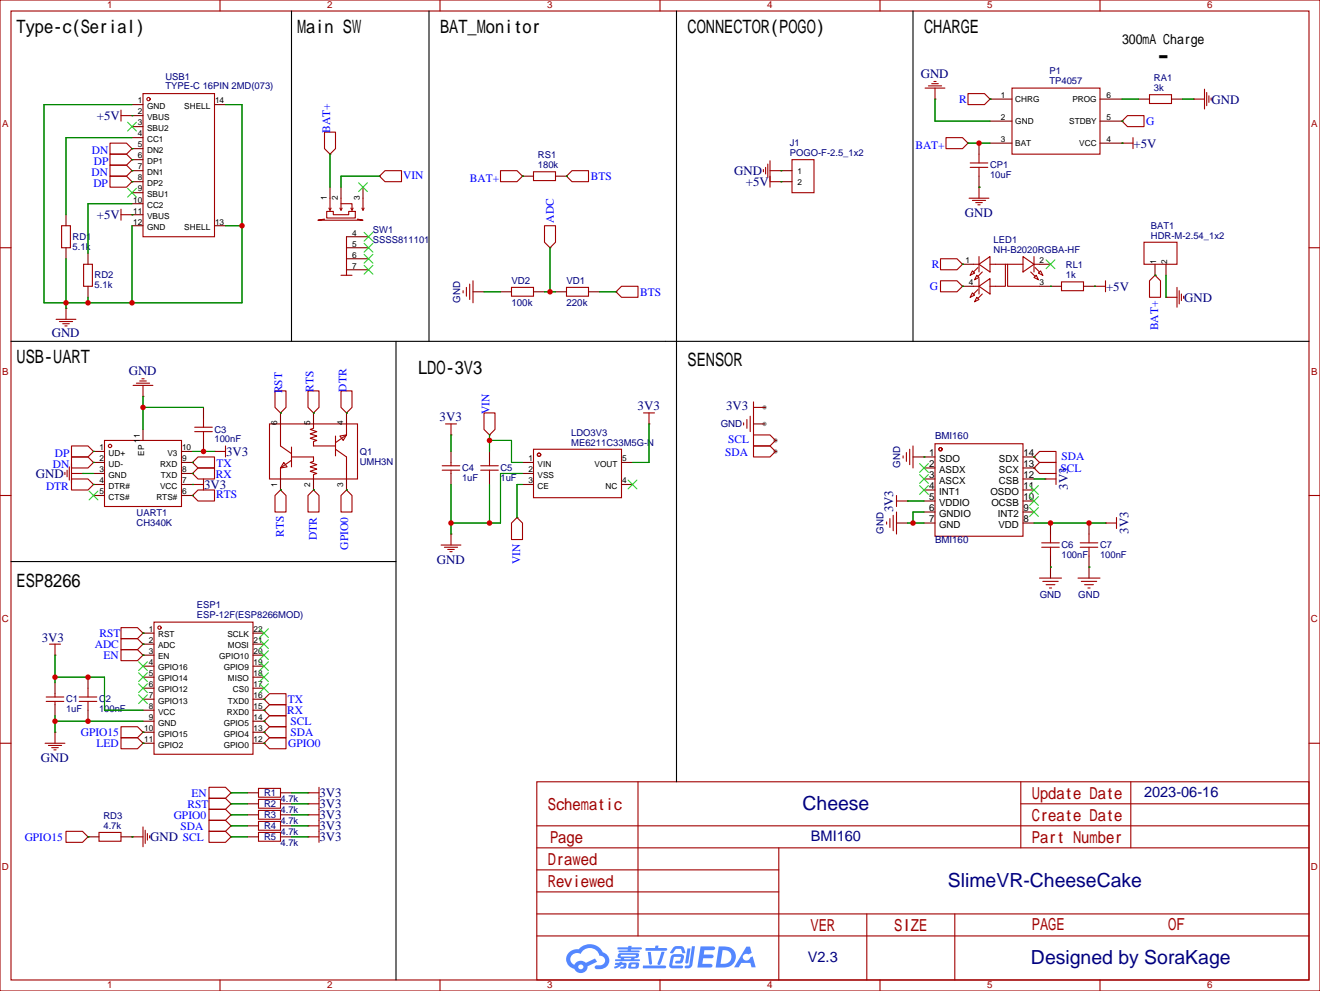
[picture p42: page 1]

OCSB 10 OSDO 11 CSB 12 SCX 13 SDX 14

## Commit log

2023-06-16 New update
    [001.1-Chocolate-Case.stl, 001.2-Chocolate-Case-With-AUX.stl, 002-BOM_BMI160_160_2023-06-16.xlsx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]
2023-06-20 SW fixed
    [003-SW.stl]
2023-06-24 fixed sw
    [003-SW.stl]
2023-07-01 Update different charge dock print files
    [ChargeDock-6port-Bottom.stl, ChargeDock-6port-Top.stl, ChargeDock-8port-Bottom.stl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]
2023-07-10 update a AUX version
    [BOM_CK_Cheese_AUX_2023-07-10.xlsx, PickAndPlace_CK_Cheese_AUX_2023-07-10.xlsx]
2023-07-25 Add pics used in assembly
2023-08-08 Optimized Charging dock
    [ChargeDock-8port-Bottom-Optimized.stl, ChargeDock-8port-Top-Optimized.stl]
2023-08-10 Fixed compatibility for SlimeVR's 085 module
    [006-BOM_AUX_Special_Special_remake.xlsx, 007-PickAndPlace_AUX_Special_remake.xlsx]
2023-08-10 Move position
    [BOM_8Port_Charging_Dock_V1.22.csv, PickAndPlace_8Port_Charging_Dock_V1.22.csv]
2023-08-10 Update a Type-c version
    [BOM__CK_Type-c_8Dock.xlsx, PickAndPlace__CK_Type-c_8Dock.xlsx]
2023-08-12 Remove components in CONN1 and BAT
    [006-BOM_AUX_Special_Special_remake.xlsx, 007-PickAndPlace_AUX_Special_remake.xlsx]
2023-09-19 Version Update
    Update a new version of CheeseCake Special Remake
    [009-BOM_CK_085_DCDC_Special_remake.xlsx, 010-PickAndPlace_CK_085_DCDC_Special_remake.xlsx]
2023-09-20 Update a new Holder
    [004-1-''CLAMP''GoPro_Holder.stl]
2023-09-20 Upload EasyEda Pro PCB design Files
2023-09-20 Update CK SP Default version
    [002-BOM_Special_Special_remake.xlsx, 002-BOM_Special_remake.xlsx, 003-PickAndPlace_Special_remake.xlsx]
2023-09-20 Fix install problem
    [004-1-''CLAMP''GoPro_Holder.stl]
2023-09-27 Update Module SK-BMI270
    [BOM_Module_SK-BMI270.xlsx, PickAndPlace_Module_SK-BMI270.xlsx]
2023-09-27 Fix BOM and CPL
    [002-BOM_BMI160_160_2023-06-16.xlsx, 003-PickAndPlace_160_2023-06-16.xlsx]
2023-09-27 Cheese is LEVEL UP to BMI270!
    [007-LVUP-BOM_CK_BMI270.xlsx, 008-LVUP-PickAndPlace_CK_BMI270.xlsx]
2023-09-27 Upload Module_SK-BMI270
    [002.BOM_Module_SK-BMI270.xlsx, 003.PickAndPlace_Module_SK-BMI270.xlsx]
2023-09-27 Update a smol version
    [005.BOM_Module_SK-BMI270_Smol.xlsx, 006.Module_SK-BMI270_Smol.xlsx]
2023-10-01 Update new case
    [001.3-Chocolate-Case_TypeC-Only.stl]
2023-10-01 Update AUX version with BMI270
    [002.BOM_CK_Cheese_AUX_2023-07-10.xlsx, 003.PickAndPlace_CK_Cheese_AUX_2023-07-10.xlsx, 005.LVUP_BOM_CK_Cheese_270_AUX.xlsx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]
2023-10-03 Update with Gerber change
    [002.BOM_SK-BMI MOD.xlsx, 003.PickAndPlace_SK-BMI MOD.xlsx, 005.BOM_SK-BMI MOD_Smol.xlsx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]
2023-11-09 Update new PCB manufacture file
    Replaced components and board design due to component shortages
2023-12-04 Update a LSM version for CheeseCake
    [BOM_LSM6DSV.xlsx, PickAndPlace_LSM6DSV.xlsx]
2023-12-04 Update LSM6DSV16X version
    [BOM_LSM6DSV.xlsx, PickAndPlace_LSM6DSV.xlsx]
2023-12-04 Support 803040 Li-Po battery and 5cm trackstraps
    [001.2-Chocolate-Case-With-AUX-For-803040-Bat.stl, 001.3-Chocolate-Case_TypeC-Only-For-803040-Bat.stl, 002-Cake-Top-3mm.stl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]
2023-12-04 Create README.md with assembly instructions
2023-12-05 Upload Type-C 3d models
    [ChargeDock-8port-Typec-Bottom.stl, ChargeDock-8port-Typec-Top.stl]
2023-12-05 Upload ICM-42688 variety of CheeseCake
    [BOM_ICM42688.xlsx, PickAndPlace_ICM42688.xlsx]
2023-12-05 Fix Type-c pin connection
2023-12-11 Update AUX board
    [002.BOM_SK-BMI MOD.xlsx, 003.PickAndPlace_SK-BMI MOD.xlsx, 005.BOM_SK-BMI MOD_Smol.xlsx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]
2023-12-11 Update LSM and ICM module
    [002.BOM_SK-ICM MOD.xlsx, 002.BOM_SK-LSM MOD.xlsx, 003.PickAndPlace_SK-ICM MOD.xlsx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]
2023-12-11 - added more info about battery
2023-12-24 Major improvements and secondary IMU case
    [001.2-Chocolate-Case-With-AUX-For-803040-Bat.stl, 001.3-Chocolate-Case_TypeC-Only-For-803040-Bat.stl, 004-''CLAMP''Holder-5cm.stl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]
2024-04-04 docs(README): add dock assembly instructions
2024-04-04 feat(holders): add holders that fit 5cm straps
    The clamp holder has both sides of strap holes
    extruded an extra 5mm each.
    The slide holder has the clip side strap hole
    extruded 1.3mm, the other side past the rails
    extended by 4.2mm and the clip side extruded by
    8.7mm to preserve integrity.
    [004-2-''CLAMP''Holder-5cm.stl, 005-1-''SLIDE''Holder-5cm.stl]
2024-04-08 Update Cheese_RV(BMI270)
    [002.BOM_BMI270-RV_Single.xlsx, 003.PickAndPlace_BMI270-RV_Single.xlsx, 005.BOM_BMI270-RV_3x2Panelization.xlsx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]
2024-04-08 Fix BOM file
    [002.BOM_BMI270-RV.xlsx.xlsx, 002.BOM_BMI270-RV_Single.xlsx, 003.PickAndPlace_BMI270-RV_Single.xlsx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]
2024-04-08 Fix BOM & CPL file
    [003.PickAndPlace_BMI270-RV.xlsx]
2024-04-22 Fixed 5cm - Models were swapped
    [004-2-''CLAMP''Holder-5cm.stl, 005-1-''SLIDE''Holder-5cm.stl]
2024-06-24 Update LSM6DSV to +mag version
    [BOM_LSM6DSV.xlsx, PickAndPlace_LSM6DSV.xlsx]
2024-06-27 Update 1St Anniversary Special Edt.
    [BOM_CK_Ann_SP.xlsx, PickAndPlace_CK_Ann_SP.xlsx]
2024-07-03 Add No-MAG BOM & CPL file
2024-07-03 Upload No-MAG version of BOM & CPL
2024-07-12 Upload new case
    [001.4-Chocolate-Case_Type-C-only_insert-nuts.stl]
2024-08-08 Update new Special Remake
    [002-BOM_Special_remake.xlsx, 002.BOM_CK_085_DCDC_Special_remake.xlsx, 003-PickAndPlace_Special_remake.xlsx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]
2024-08-08 Change file str
    [002.BOM_CK_085_DCDC_Special_remake.xlsx, 003.PickAndPlace_CK_085_DCDC_Special_remake.xlsx]
2024-08-08 Update new version of special remake
    [002.BOM_CK_085_DCDC_Special_remake.xlsx, 003.PickAndPlace_CK_085_DCDC_Special_remake.xlsx]
2024-12-08 Update new model for specific strap
    [004-3-''CLAMP''Holder-wide.stl, 005-2-''SLIDE''Holder-wide.stl]
2025-01-19 Update BOM file
    Fix shortage of M3406-ADJ by change it to MT3406
    [002.BOM_BMI270-RV.xlsx.xlsx, 002.BOM_CK_085_DCDC_Special_remake.xlsx, 003.PickAndPlace_BMI270-RV.xlsx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]
2025-01-19 Update BOM File
    [009-BOM_CK_085_DCDC_Special_remake.xlsx, 010-PickAndPlace_CK_085_DCDC_Special_remake.xlsx]
